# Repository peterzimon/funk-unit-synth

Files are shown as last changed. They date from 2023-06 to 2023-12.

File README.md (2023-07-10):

# Shmøergh Funk Live One — 6 voice paraphonic synthesizer

Shmøergh Funk Live One is a 6 voice (mostly) digitally controlled paraphonic
analog synthesizer. Its purposefully built with limitations so it's great for
live performances with quick changes in settings without presets or menu diving. It
has a lot of simple but effective ways to modulate the filter cutoff which makes
it great for funk performances. Because of its simplicity it's also cool to get
started with synthesis.

**Status:** WORK IN PROGRESS

**Latest version:** 1.1

## Features

- 6 voices (DCOs) controlled by a Raspberry Pi Pico
- Sawtooth, square, narrow pulse and fixed rate pulse with modulated square waveforms
- Analog signal path
- External filter connection with selectable various modulation sources (envelope, velocity, analog LFO, modwheel, keyboard tracking). Steiner-Parker
filter schematics and PCB is included
- 12bit digital ADSR with simplified envelope controls
- Built-in analog VCA with optional external VCA connections
- Monophonic, 3-voice unison with detune and 6-voice paraphonic modes
- MIDI input
- Eurorack compatible PCB sizing

Note: schematics does not include power supply

## References

- [Polykit DCO design](https://github.com/polykit/pico-dco)
- [The design of the Roland Juno synthesizes](https://blog.thea.codes/the-design-of-the-juno-dco/)
- [Steiner-Parker Filter](https://yusynth.net/Modular/EN/STEINERVCF/index-v2.html)

## License & info

Version: 1.1.0
Author: Peter Zimon
Copyright: 2023
Licence: MIT

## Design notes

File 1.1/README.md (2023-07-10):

# V1.1

- Added DC blocking to mixer inputs to avoid shifting waveforms by f=0Hz frequency DCOs
- Decreased sawtooth and square mixer amplification to avoid distortion

## License & info

Version: 1.0.0
Author: Peter Zimon
Copyright: 2023
Licence: MIT

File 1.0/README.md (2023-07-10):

# V1.0

- Complete schematics
- Fundamentals of code is implemented for handling 6 voices
- ADSR implemented
- MUX to handle switches
- All basic functionalities are working

# To Be Done

- Filter modulation is untested

## License & info

Version: 1.0.0
Author: Peter Zimon
Copyright: 2023
Licence: MIT

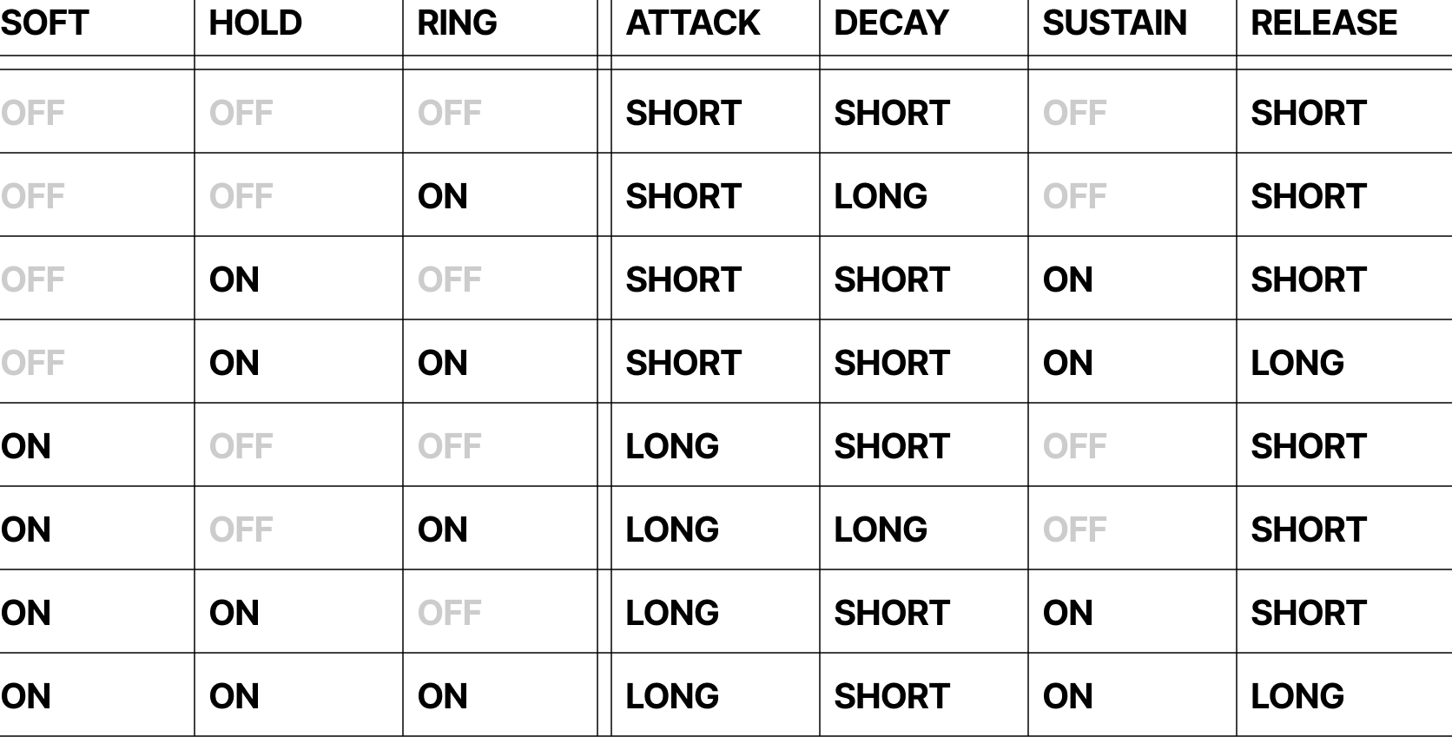
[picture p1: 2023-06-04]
1.0/docs/adsr-truthtable.png

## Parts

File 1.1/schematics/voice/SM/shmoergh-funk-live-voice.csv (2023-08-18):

Comment | Designator | Footprint | LCSC
100n | C1,C2,C3 | Capacitor_SMD:C_0805_2012Metric | C49678
4.7k | R1 | PCM_Resistor_SMD_AKL:R_0805_2012Metric | C17673
330k | R10 | PCM_Resistor_SMD_AKL:R_0805_2012Metric | C17629
15k | R12 | PCM_Resistor_SMD_AKL:R_0805_2012Metric | C17475
10k | R2,R13 | PCM_Resistor_SMD_AKL:R_0805_2012Metric | C17414
200k | R3,R7 | PCM_Resistor_SMD_AKL:R_0805_2012Metric | C17539
1k | R4 | PCM_Resistor_SMD_AKL:R_0805_2012Metric | C17513
2.2k | R5 | PCM_Resistor_SMD_AKL:R_0805_2012Metric | C17520
100k | R6,R11 | PCM_Resistor_SMD_AKL:R_0805_2012Metric | C149504
470k | R8,R9 | PCM_Resistor_SMD_AKL:R_0805_2012Metric | C17709

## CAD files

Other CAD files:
1.0/case/wooden-case-proto.blend

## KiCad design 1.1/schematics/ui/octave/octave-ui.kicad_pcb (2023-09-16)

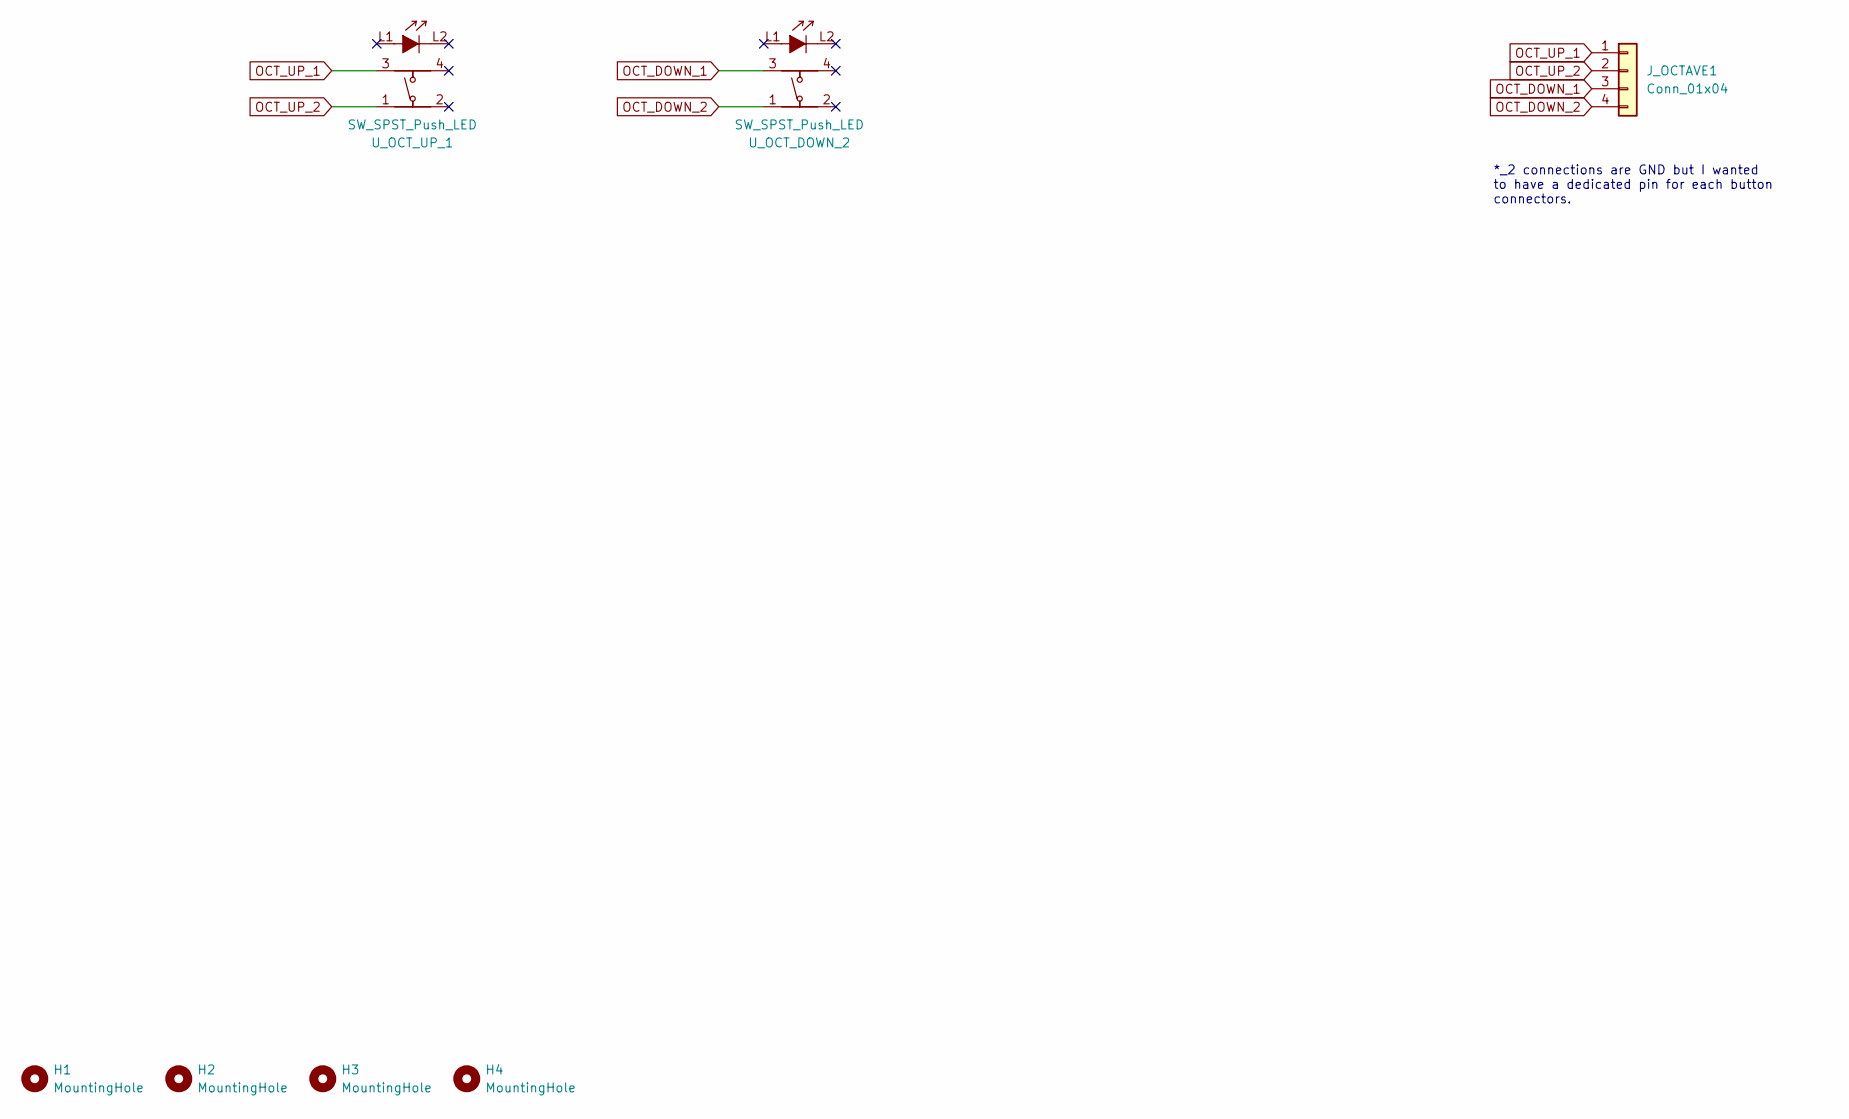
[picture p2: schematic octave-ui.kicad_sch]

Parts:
H1, H2, H3, H4: MountingHole; MountingHole_4mm
J_OCTAVE1: Conn_01x04; NSL25_01x04_Vertical
U_OCT_DOWN_2: SW_SPST_Push_LED; SPST_Narrow_Circular_Pushbutton_LED
U_OCT_UP_1: SW_SPST_Push_LED; SPST_Narrow_Circular_Pushbutton_LED

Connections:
OCT_DOWN_1: J_OCTAVE1.3, U_OCT_DOWN_2.3
OCT_DOWN_2: J_OCTAVE1.4, U_OCT_DOWN_2.1
OCT_UP_1: J_OCTAVE1.1, U_OCT_UP_1.3
OCT_UP_2: J_OCTAVE1.2, U_OCT_UP_1.1

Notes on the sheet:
*_2 connections are GND but I wanted to have a dedicated pin for each button connectors.

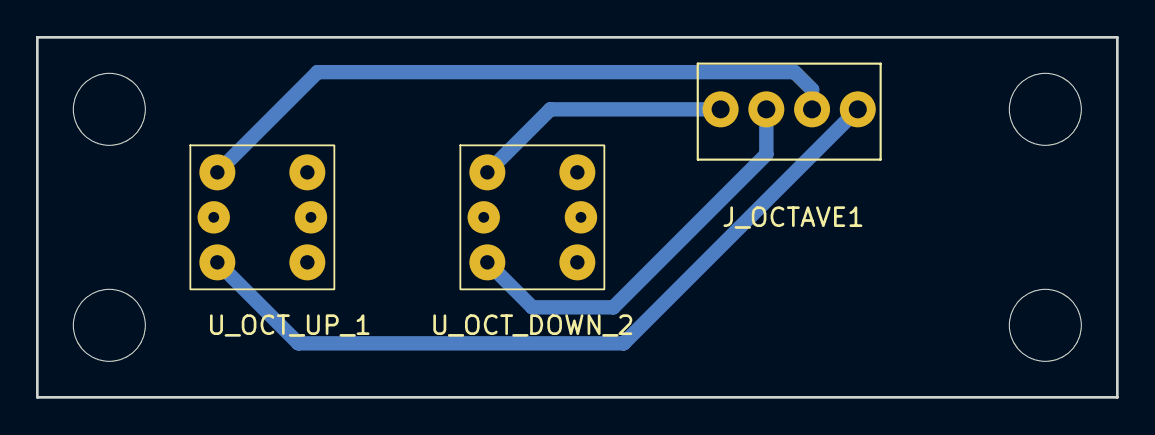
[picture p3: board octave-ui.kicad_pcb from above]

Board: 2 copper layers, 60.0 x 20.0 mm, 7 parts (0 on the bottom side), 4 nets.

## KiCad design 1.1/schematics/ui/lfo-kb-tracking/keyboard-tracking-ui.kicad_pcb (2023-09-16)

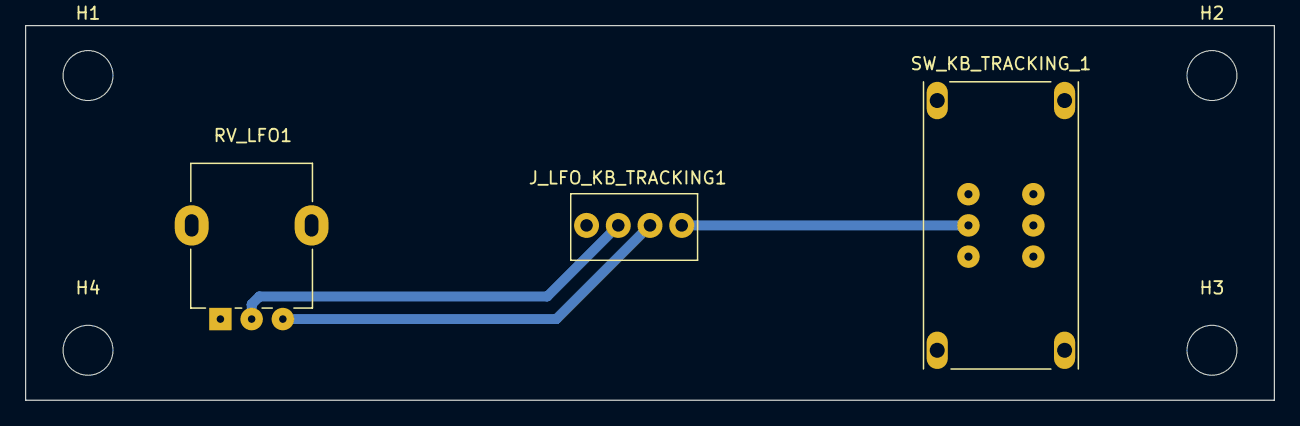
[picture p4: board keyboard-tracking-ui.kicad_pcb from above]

Board: 2 copper layers, 100.0 x 30.0 mm, 7 parts (0 on the bottom side), 4 nets.

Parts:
H1, H2, H3, H4: MountingHole; MountingHole_4mm
J_LFO_KB_TRACKING1: Conn_01x04; NSL25_01x04_Vertical
RV_LFO1: 100k; Potentiometer_Alpha_RD901F-40-00D_Single_Vertical
SW_KB_TRACKING_1: SW_DPDT_x2; DPDT Korg Style Switch

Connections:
GND: J_LFO_KB_TRACKING1.4, RV_LFO1.1, SW_KB_TRACKING_1.5 (C)
KB_TRACKING: J_LFO_KB_TRACKING1.1, SW_KB_TRACKING_1.3 (B)
LFO_IN: J_LFO_KB_TRACKING1.2, RV_LFO1.3
LFO_OUT: J_LFO_KB_TRACKING1.3, RV_LFO1.2

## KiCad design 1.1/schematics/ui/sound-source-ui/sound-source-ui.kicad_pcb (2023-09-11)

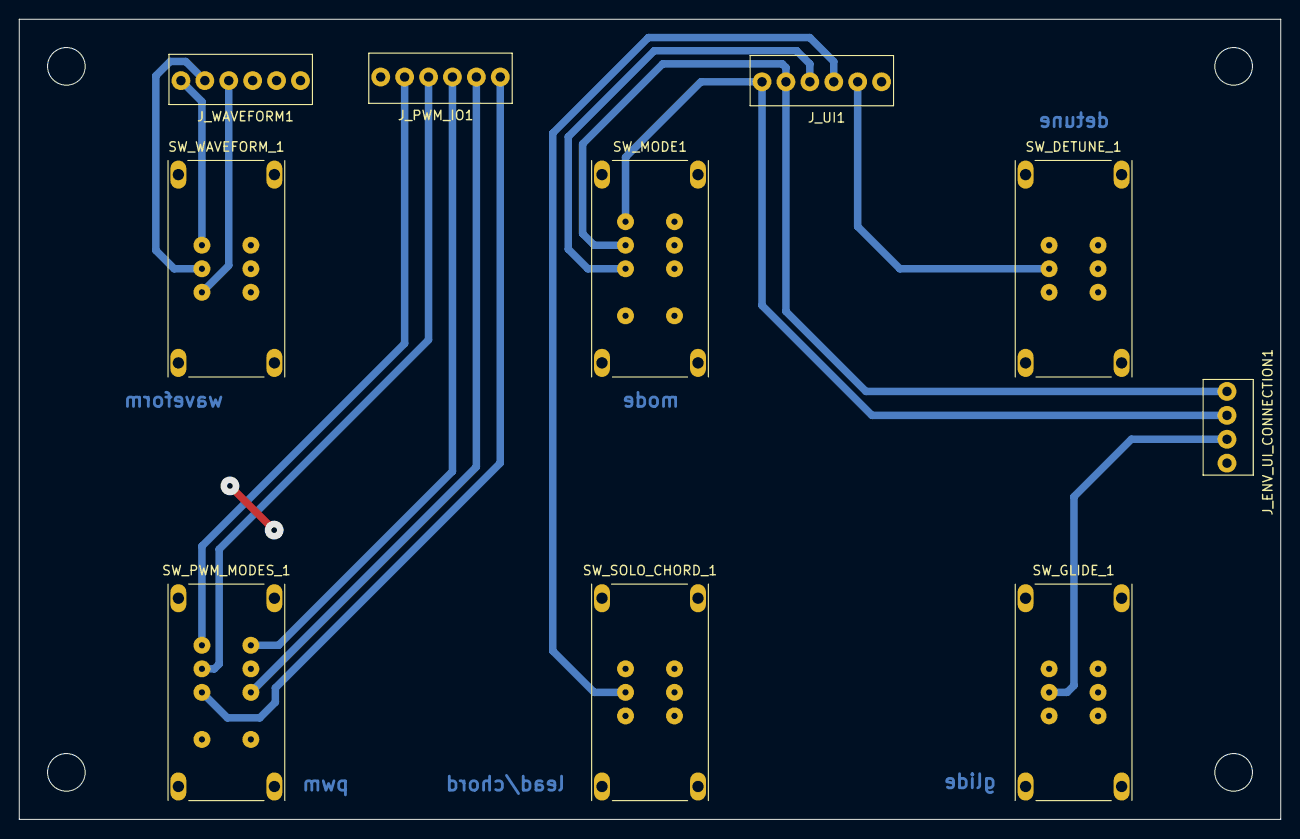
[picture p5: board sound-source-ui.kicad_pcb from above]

Board: 2 copper layers, 134.0 x 85.0 mm, 14 parts (0 on the bottom side), 15 nets.

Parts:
H1, H2, H3, H4: MountingHole; MountingHole_4mm
J_ENV_UI_CONNECTION1: Conn_01x04; NSL25_01x04_Vertical
J_PWM_IO1: Conn_01x06; NSL25_01x06_Vertical
J_UI1: Conn_01x06; NSL25_01x06_Vertical
J_WAVEFORM1: Conn_01x03; NSL25_01x06_Vertical
SW_DETUNE_1: SW_DPDT_x2; DPDT Korg Style Switch
SW_GLIDE_1: SW_DPDT_x2; DPDT Korg Style Switch
SW_MODE1: SW_DP3T; DP3T Korg Style Switch
SW_PWM_MODES_1: SW_DP3T; DP3T Korg Style Switch
SW_SOLO_CHORD_1: SW_DPDT_x2; DPDT Korg Style Switch
SW_WAVEFORM_1: SW_DPDT_x2; DPDT Korg Style Switch

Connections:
1.5V: J_ENV_UI_CONNECTION1.1, J_UI1.2, SW_MODE1.2
+3.3V: J_ENV_UI_CONNECTION1.2, J_UI1.1, SW_MODE1.1
DETUNE: J_UI1.5, SW_DETUNE_1.3 (B)
GLIDE: J_ENV_UI_CONNECTION1.3, SW_GLIDE_1.3 (B)
GND: J_ENV_UI_CONNECTION1.4, J_PWM_IO1.6, J_UI1.6, SW_DETUNE_1.5 (C), SW_GLIDE_1.5 (C), SW_MODE1.4, SW_PWM_MODES_1.4, SW_PWM_MODES_1.6, SW_PWM_MODES_1.8, SW_SOLO_CHORD_1.5 (C)
MODE: J_UI1.3, SW_MODE1.3
PULSE_WIDTH: J_PWM_IO1.1, SW_PWM_MODES_1.3
PWM_LFO: J_PWM_IO1.3, SW_PWM_MODES_1.5
PWM_LFO_BIAS: J_PWM_IO1.5, SW_PWM_MODES_1.1
PWM_NARROW_BIAS: J_PWM_IO1.4, SW_PWM_MODES_1.2
PWM_OUT: J_PWM_IO1.2, SW_PWM_MODES_1.7
SAW_IN: J_WAVEFORM1.3, SW_WAVEFORM_1.5 (C)
SOLO_CHORD: J_UI1.4, SW_SOLO_CHORD_1.3 (B)
SQR_IN: J_WAVEFORM1.1, SW_WAVEFORM_1.1 (A)
WAVEFORM_OUT: J_WAVEFORM1.2, SW_WAVEFORM_1.3 (B)

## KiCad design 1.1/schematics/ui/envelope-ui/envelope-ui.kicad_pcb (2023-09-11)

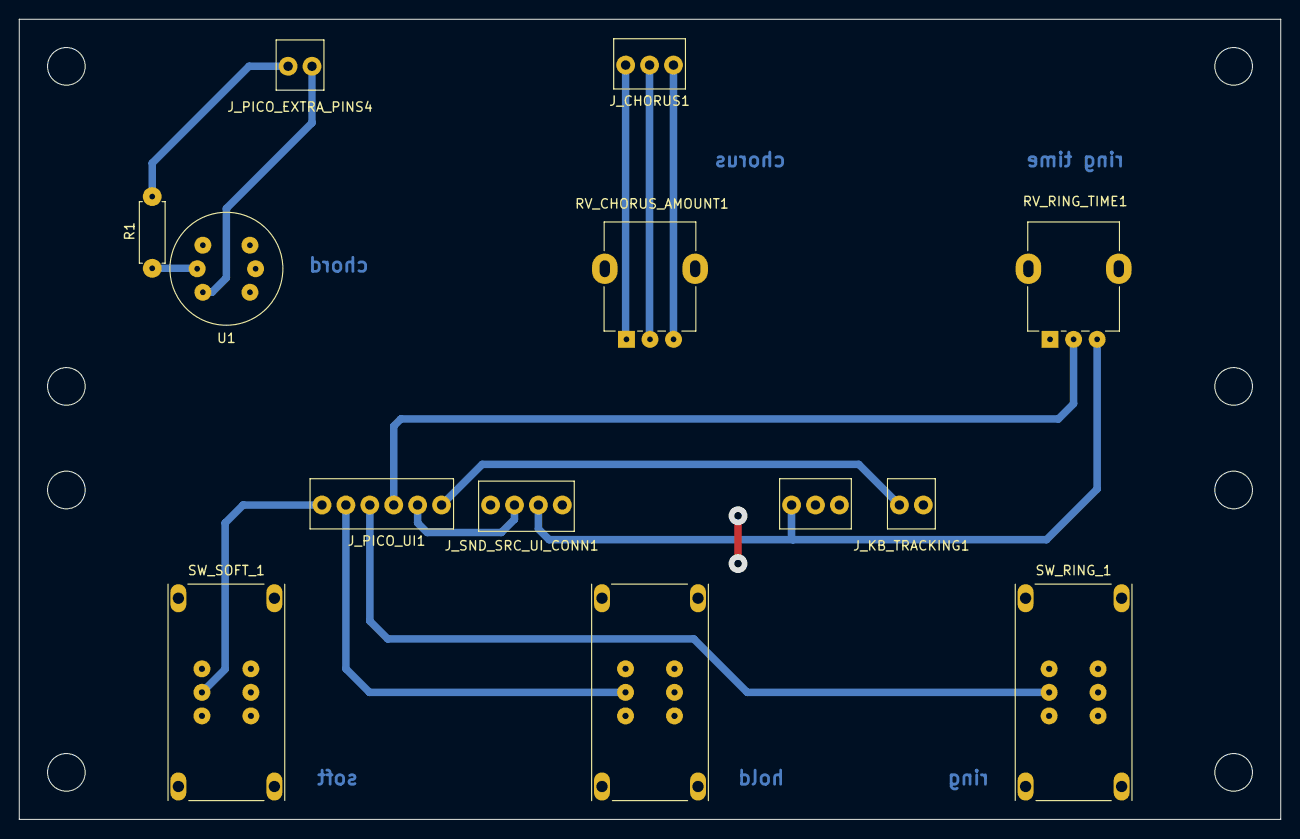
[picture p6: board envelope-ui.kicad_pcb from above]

Board: 2 copper layers, 134.0 x 85.0 mm, 21 parts (0 on the bottom side), 14 nets.

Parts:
H1, H2, H3, H4, H5, H6, H7, H8: MountingHole; MountingHole_4mm
J_CHORUS1: Conn_01x03; NSL25_01x03_Vertical
J_KB_TRACKING1: Conn_01x02; NSL25_01x02_Vertical
J_PICO_EXTRA_PINS4: Conn_01x02; NSL25_01x02_Vertical
J_PICO_UI1: Conn_01x06; NSL25_01x06_Vertical
J_PWR1: Conn_01x03; NSL25_01x03_Vertical
J_SND_SRC_UI_CONN1: Conn_01x04; NSL25_01x04_Vertical
R1: R; R_Axial_DIN0207_L6.3mm_D2.5mm_P7.62mm_Horizontal
RV_CHORUS_AMOUNT1: 100k; Potentiometer_Alpha_RD901F-40-00D_Single_Vertical
RV_RING_TIME1: 100k; Potentiometer_Alpha_RD901F-40-00D_Single_Vertical
SW_HOLD_1: SW_DPDT_x2; DPDT Korg Style Switch
SW_RING_1: SW_DPDT_x2; DPDT Korg Style Switch
SW_SOFT_1: SW_DPDT_x2; DPDT Korg Style Switch
U1: SW_SPST_Push_LED; SPST_Circular_Pushbutton_LED

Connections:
+3.3V: J_PWR1.1, J_SND_SRC_UI_CONN1.2, RV_RING_TIME1.3
CHORD_BTN: J_PICO_EXTRA_PINS4.2, U1.3
CHORD_LED: J_PICO_EXTRA_PINS4.1, R1.1
CHORUS_1: J_CHORUS1.1, RV_CHORUS_AMOUNT1.1
CHORUS_2: J_CHORUS1.2, RV_CHORUS_AMOUNT1.2
CHORUS_3: J_CHORUS1.3, RV_CHORUS_AMOUNT1.3
GLIDE: J_PICO_UI1.5, J_SND_SRC_UI_CONN1.3
GND: J_KB_TRACKING1.2, J_PWR1.2, J_PWR1.3, J_SND_SRC_UI_CONN1.4, RV_RING_TIME1.1, SW_HOLD_1.5 (C), SW_RING_1.5 (C), SW_SOFT_1.5 (C), U1.1, U1.L2
HOLD: J_PICO_UI1.2, SW_HOLD_1.3 (B)
KB_TRACKING: J_KB_TRACKING1.1, J_PICO_UI1.6
unnamed: R1.2, U1.L1
RING: J_PICO_UI1.3, SW_RING_1.3 (B)
RING_TIME: J_PICO_UI1.4, RV_RING_TIME1.2
SOFT: J_PICO_UI1.1, SW_SOFT_1.3 (B)

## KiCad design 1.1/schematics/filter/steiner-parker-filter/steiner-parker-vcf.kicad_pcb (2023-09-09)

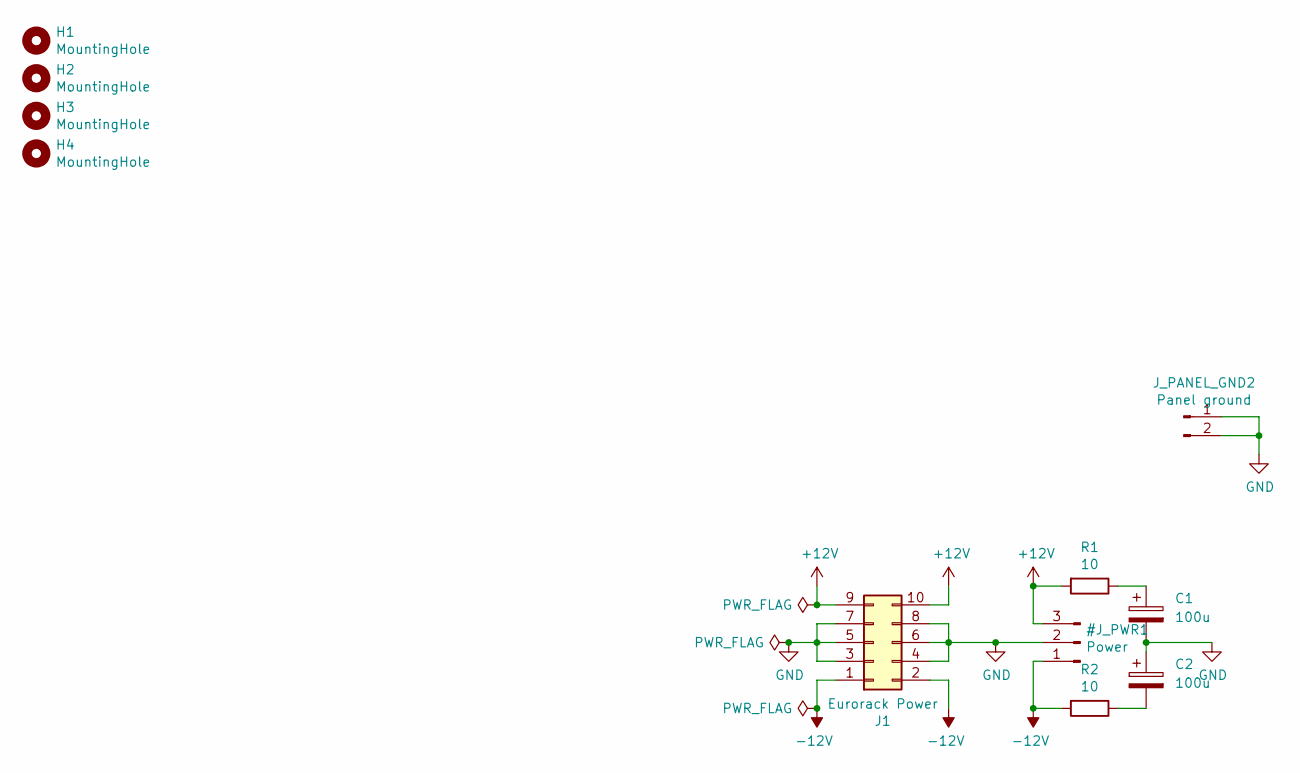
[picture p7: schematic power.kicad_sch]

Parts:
C1, C2: 100u; CP_Radial_D6.3mm_P2.50mm
H1, H2, H3, H4: MountingHole; MountingHole_3mm_Pad
J1: Eurorack Power; IDC-Header_2x05_P2.54mm_Vertical
J_PANEL_GND2: Panel ground; NSL25_01x02_Vertical
R1, R2: 10; R_Axial_DIN0207_L6.3mm_D2.5mm_P7.62mm_Horizontal

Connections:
unnamed: C1.1, R1.1
unnamed: C2.2, R2.1

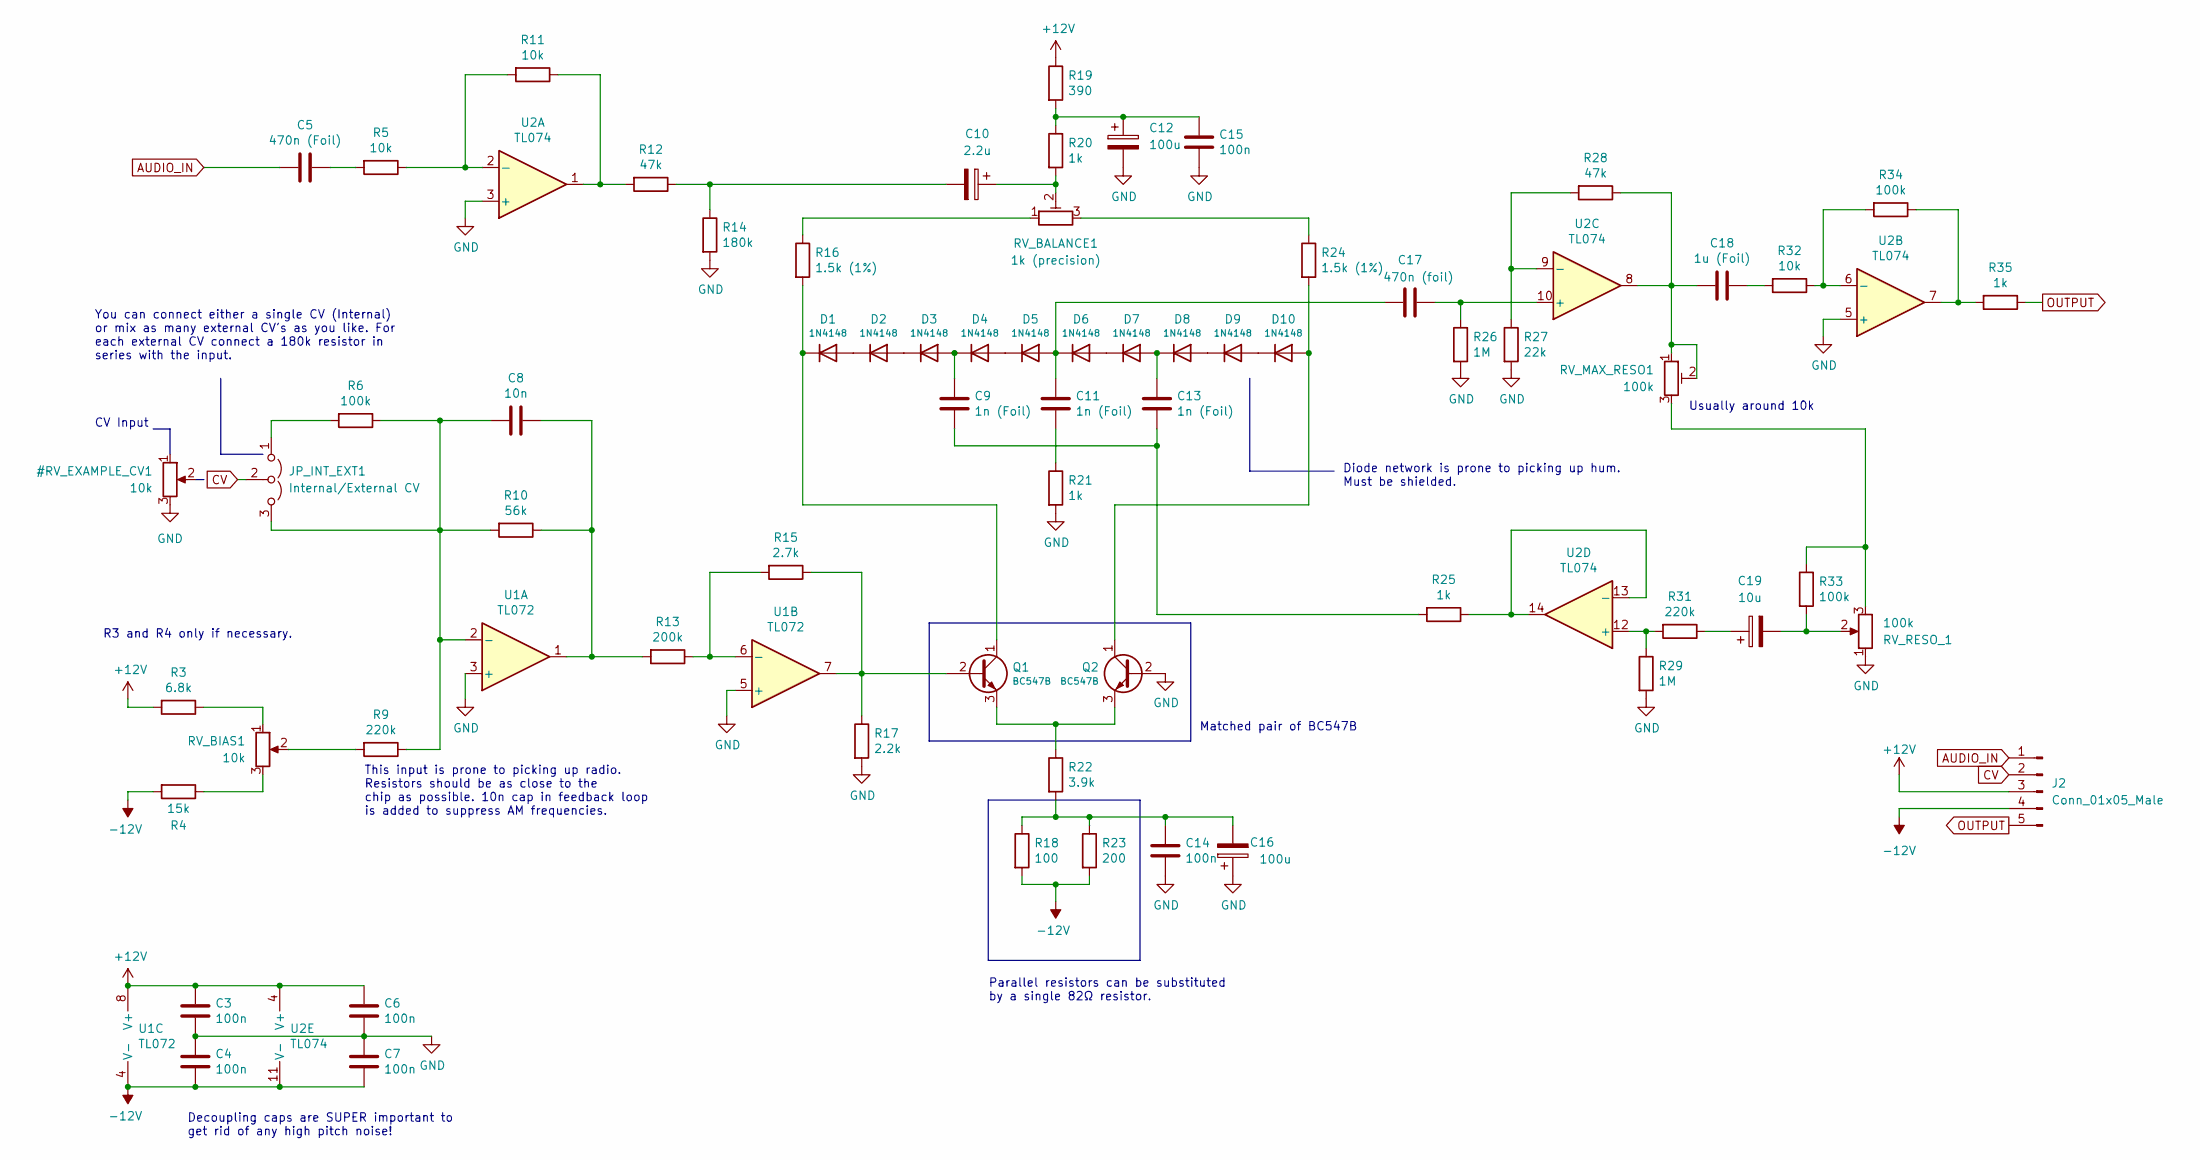
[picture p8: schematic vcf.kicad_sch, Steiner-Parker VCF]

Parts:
C3, C4, C6, C7, C14, C15: 100n; C_Disc_D3.0mm_W2.0mm_P2.50mm
C5: 470n (Foil); C_Rect_L7.0mm_W2.5mm_P5.00mm
C8: 10n; C_Disc_D3.0mm_W2.0mm_P2.50mm
C9, C11, C13: 1n (Foil); C_Rect_L7.0mm_W2.5mm_P5.00mm
C10: 2.2u; CP_Radial_D6.3mm_P2.50mm
C12, C16: 100u; CP_Radial_D6.3mm_P2.50mm
C17: 470n (foil); C_Rect_L7.0mm_W2.5mm_P5.00mm
C18: 1u (Foil); C_Rect_L7.0mm_W4.5mm_P5.00mm
C19: 10u; CP_Radial_D6.3mm_P2.50mm
D1, D2, D3, D4, D5, D6, D7, D8, D9, D10: 1N4148; D_DO-35_SOD27_P7.62mm_Horizontal
J2: Conn_01x05_Male; NSL25_01x05_Vertical
JP_INT_EXT1: Internal/External CV; PinSocket_1x03_P2.54mm_Vertical
Q1, Q2: BC547B; TO-92_Inline_Wide
R3: 6.8k; R_Axial_DIN0207_L6.3mm_D2.5mm_P7.62mm_Horizontal
R4: 15k; R_Axial_DIN0207_L6.3mm_D2.5mm_P7.62mm_Horizontal
R5, R11, R32: 10k; R_Axial_DIN0207_L6.3mm_D2.5mm_P7.62mm_Horizontal
R6, R33, R34: 100k; R_Axial_DIN0207_L6.3mm_D2.5mm_P7.62mm_Horizontal
R9, R31: 220k; R_Axial_DIN0207_L6.3mm_D2.5mm_P7.62mm_Horizontal
R10: 56k; R_Axial_DIN0207_L6.3mm_D2.5mm_P7.62mm_Horizontal
R12, R28: 47k; R_Axial_DIN0207_L6.3mm_D2.5mm_P7.62mm_Horizontal
R13: 200k; R_Axial_DIN0207_L6.3mm_D2.5mm_P7.62mm_Horizontal
R14: 180k; R_Axial_DIN0207_L6.3mm_D2.5mm_P7.62mm_Horizontal
R15: 2.7k; R_Axial_DIN0207_L6.3mm_D2.5mm_P7.62mm_Horizontal
R16, R24: 1.5k (1%); R_Axial_DIN0207_L6.3mm_D2.5mm_P7.62mm_Horizontal
R17: 2.2k; R_Axial_DIN0207_L6.3mm_D2.5mm_P7.62mm_Horizontal
R18: 100; R_Axial_DIN0207_L6.3mm_D2.5mm_P7.62mm_Horizontal
R19: 390; R_Axial_DIN0207_L6.3mm_D2.5mm_P7.62mm_Horizontal
R20, R21, R25, R35: 1k; R_Axial_DIN0207_L6.3mm_D2.5mm_P7.62mm_Horizontal
R22: 3.9k; R_Axial_DIN0207_L6.3mm_D2.5mm_P7.62mm_Horizontal
R23: 200; R_Axial_DIN0207_L6.3mm_D2.5mm_P7.62mm_Horizontal
R26, R29: 1M; R_Axial_DIN0207_L6.3mm_D2.5mm_P7.62mm_Horizontal
R27: 22k; R_Axial_DIN0207_L6.3mm_D2.5mm_P7.62mm_Horizontal
RV_BALANCE1: 1k (precision); Potentiometer_Bourns_3296W_Vertical
RV_BIAS1: 10k; Potentiometer_Runtron_RM-065_Vertical
RV_MAX_RESO1: 100k; Potentiometer_Runtron_RM-065_Vertical
RV_RESO_1: 100k; NSL25_01x03_Vertical
U1: TL072; DIP-8_W7.62mm_LongPads
U2: TL074; DIP-14_W7.62mm_LongPads

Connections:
AUDIO_IN: C5.2, J2.1
CV: J2.2, JP_INT_EXT1.2 (C)
unnamed: C5.1, R5.2
unnamed: C8.1, R10.1, R13.2, U1.1
unnamed: C10.1, R20.2, RV_BALANCE1.2
unnamed: C10.2, R12.1, R14.1
unnamed: C11.2, R21.1
unnamed: C12.1, C15.1, R19.2, R20.1
unnamed: C9.2, C13.2, R25.2
unnamed: C14.1, C16.2, R18.1, R22.2, R23.1
unnamed: C18.1, R32.2
unnamed: C18.2, R28.1, RV_MAX_RESO1.1, RV_MAX_RESO1.2, U2.8
unnamed: C19.1, R31.1
unnamed: C19.2, R33.2, RV_RESO_1.2
unnamed: D1.2 (A), D2.1 (K)
unnamed: D1.1 (K), Q1.1 (C), R16.2
unnamed: D2.2 (A), D3.1 (K)
unnamed: C9.1, D3.2 (A), D4.1 (K)
unnamed: D4.2 (A), D5.1 (K)
unnamed: C11.1, C17.2, D5.2 (A), D6.1 (K)
unnamed: D6.2 (A), D7.1 (K)
unnamed: C13.1, D7.2 (A), D8.1 (K)
unnamed: D8.2 (A), D9.1 (K)
unnamed: D10.2 (A), Q2.1 (C), R24.2
unnamed: D9.2 (A), D10.1 (K)
unnamed: JP_INT_EXT1.1 (A), R6.2
unnamed: C8.2, JP_INT_EXT1.3 (B), R6.1, R9.1, R10.2, U1.2 (-)
unnamed: Q1.2 (B), R15.1, R17.1, U1.7
unnamed: Q1.3 (E), Q2.3 (E), R22.1
unnamed: R3.1, RV_BIAS1.1
unnamed: R4.1, RV_BIAS1.3
unnamed: R9.2, RV_BIAS1.2
unnamed: R11.1, R12.2, U2.1
unnamed: R16.1, RV_BALANCE1.1
unnamed: R24.1, RV_BALANCE1.3
unnamed: R33.1, RV_MAX_RESO1.3, RV_RESO_1.3
unnamed: R34.1, R35.2, U2.7
unnamed: R13.1, R15.2, U1.6 (-)
unnamed: R5.1, R11.2, U2.2 (-)
unnamed: R32.1, R34.2, U2.6 (-)
unnamed: C17.1, R26.1, U2.10 (+)
unnamed: R27.1, R28.2, U2.9 (-)
unnamed: R29.1, R31.2, U2.12 (+)
unnamed: R25.1, U2.13 (-), U2.14
OUTPUT: J2.5, R35.1

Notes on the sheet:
CV Input
This input is prone to picking up radio. Resistors should be as close to the chip as possible. 10n cap in feedback loop is added to suppress AM frequencies.
Decoupling caps are SUPER important to get rid of any high pitch noise!
Matched pair of BC547B
R3 and R4 only if necessary.
Parallel resistors can be substituted by a single 82Ω resistor.
Usually around 10k
You can connect either a single CV (Internal) or mix as many external CV's as you like. For each external CV connect a 180k resistor in series with the input.
Diode network is prone to picking up hum. Must be shielded.

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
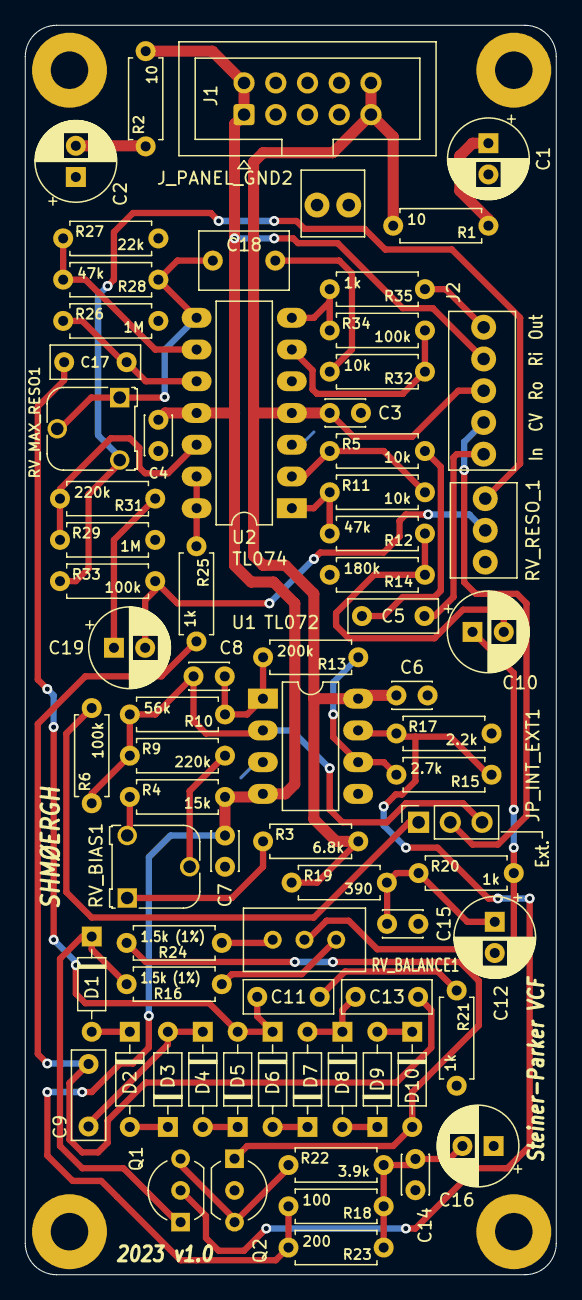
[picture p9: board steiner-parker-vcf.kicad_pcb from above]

Board: 2 copper layers, 42.5 x 100.0 mm, 77 parts (0 on the bottom side), 50 nets.

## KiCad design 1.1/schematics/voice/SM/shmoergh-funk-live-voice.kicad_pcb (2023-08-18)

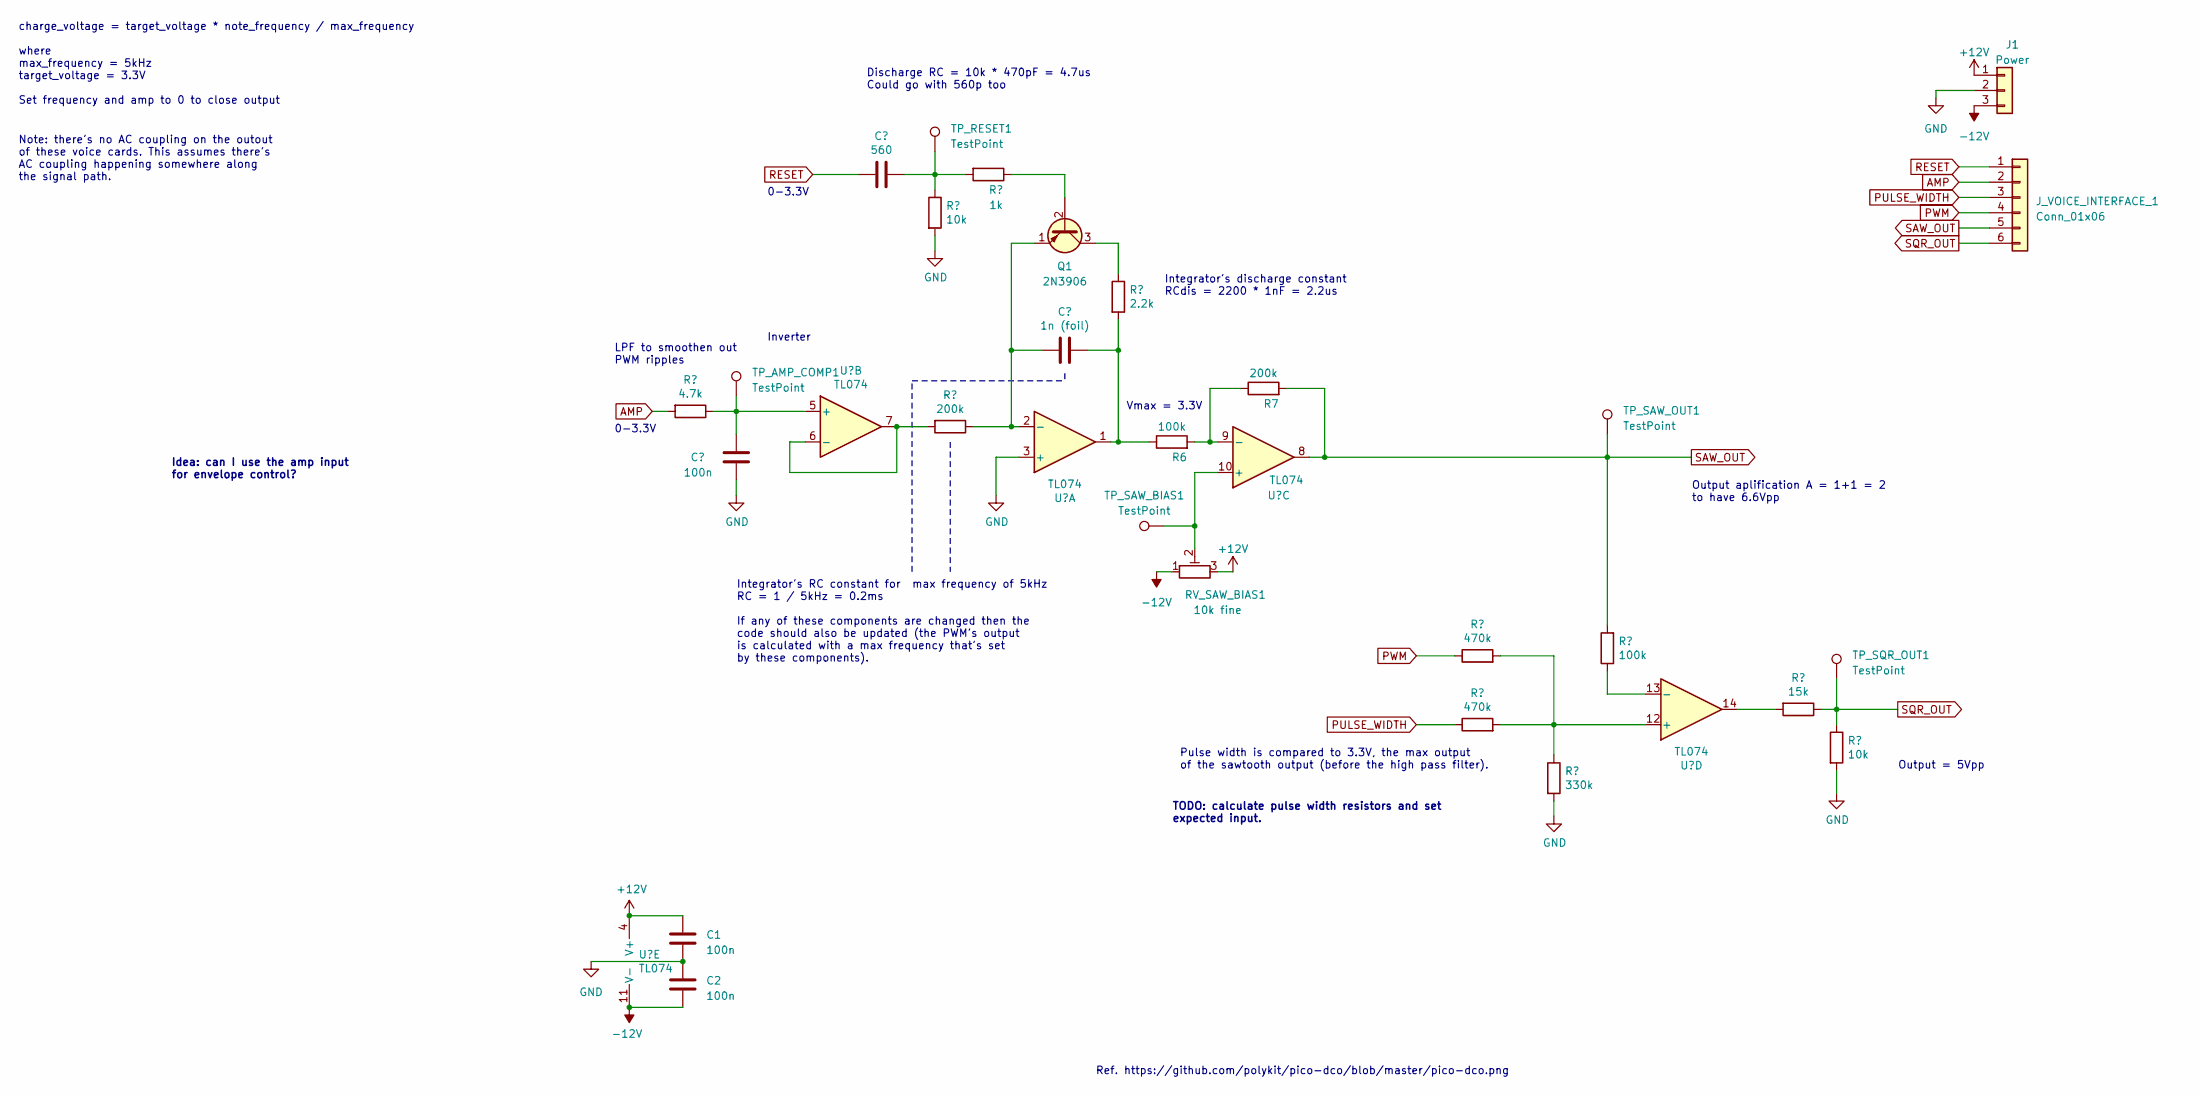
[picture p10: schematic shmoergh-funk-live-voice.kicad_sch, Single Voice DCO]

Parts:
C1, C2, C3: 100n; C_0805_2012Metric; LCSC C49678
C4: 560; C_Disc_D3.4mm_W2.1mm_P2.50mm
C5: 1n (foil); C_Rect_L7.2mm_W4.5mm_P5.00mm_FKS2_FKP2_MKS2_MKP2
J1: Power; PinHeader_1x03_P2.54mm_Vertical
J_VOICE_INTERFACE_1: Conn_01x06; PinHeader_1x06_P2.54mm_Vertical
Q1: 2N3906; TO-92L_Inline_Wide
R1: 4.7k; R_0805_2012Metric; LCSC C17673
R2, R13: 10k; R_0805_2012Metric; LCSC C17414
R3, R7: 200k; R_0805_2012Metric; LCSC C17539
R4: 1k; R_0805_2012Metric; LCSC C17513
R5: 2.2k; R_0805_2012Metric; LCSC C17520
R6, R11: 100k; R_0805_2012Metric; LCSC C149504
R8, R9: 470k; R_0805_2012Metric; LCSC C17709
R10: 330k; R_0805_2012Metric; LCSC C17629
R12: 15k; R_0805_2012Metric; LCSC C17475
RV_SAW_BIAS1: 10k fine; Potentiometer_ACP_CA6-H2,5_Horizontal
TP_AMP_COMP1: TestPoint; Pin_D0.7mm_L6.5mm_W1.8mm_FlatFork
TP_RESET1: TestPoint; Pin_D0.7mm_L6.5mm_W1.8mm_FlatFork
TP_SAW_BIAS1: TestPoint; Pin_D0.7mm_L6.5mm_W1.8mm_FlatFork
TP_SAW_OUT1: TestPoint; Pin_D0.7mm_L6.5mm_W1.8mm_FlatFork
TP_SQR_OUT1: TestPoint; Pin_D0.7mm_L6.5mm_W1.8mm_FlatFork
U1: TL074; DIP-14_W7.62mm_Socket_LongPads

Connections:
+12V: C1.1, J1.1, RV_SAW_BIAS1.3, U1.4 (V+)
-12V: C2.2, J1.3, RV_SAW_BIAS1.1, U1.11 (V-)
AMP: J_VOICE_INTERFACE_1.2, R1.2
GND: C1.2, C2.1, C3.2, J1.2, R2.2, R10.2, R13.2, U1.3 (+)
unnamed: C4.1, R2.1, R4.2, TP_RESET1.1
unnamed: C5.1, R5.2, R6.1, U1.1
unnamed: Q1.2 (B), R4.1
unnamed: Q1.3 (C), R5.1
unnamed: C5.2, Q1.1 (E), R3.1, U1.2 (-)
unnamed: R12.2, U1.14
unnamed: C3.1, R1.1, TP_AMP_COMP1.1, U1.5 (+)
unnamed: R3.2, U1.6 (-), U1.7
unnamed: RV_SAW_BIAS1.2, TP_SAW_BIAS1.1, U1.10 (+)
unnamed: R6.2, R7.1, U1.9 (-)
unnamed: R8.2, R9.2, R10.1, U1.12 (+)
unnamed: R11.1, U1.13 (-)
PULSE_WIDTH: J_VOICE_INTERFACE_1.3, R9.1
PWM: J_VOICE_INTERFACE_1.4, R8.1
RESET: C4.2, J_VOICE_INTERFACE_1.1
SAW_OUT: J_VOICE_INTERFACE_1.5, R7.2, R11.2, TP_SAW_OUT1.1, U1.8
SQR_OUT: J_VOICE_INTERFACE_1.6, R12.1, R13.1, TP_SQR_OUT1.1

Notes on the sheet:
Pulse width is compared to 3.3V, the max output of the sawtooth output (before the high pass filter).
Inverter
Idea: can I use the amp input for envelope control?
Vmax = 3.3V
TODO: calculate pulse width resistors and set expected input.
Output = 5Vpp
0-3.3V
charge_voltage = target_voltage * note_frequency / max_frequency where max_frequency = 5kHz target_voltage = 3.3V Set frequency and amp to 0 to close output
Output aplification A = 1+1 = 2 to have 6.6Vpp
Integrator's discharge constant RCdis = 2200 * 1nF = 2.2us
Note: there's no AC coupling on the outout of these voice cards. This assumes there's AC coupling happening somewhere along the signal path.
LPF to smoothen out PWM ripples
Discharge RC = 10k * 470pF = 4.7us Could go with 560p too
Integrator's RC constant for max frequency of 5kHz RC = 1 / 5kHz = 0.2ms If any of these components are changed then the code should also be updated (the PWM's output is calculated with a max frequency that's set by these components).
Ref. https://github.com/polykit/pico-dco/blob/master/pico-dco.png

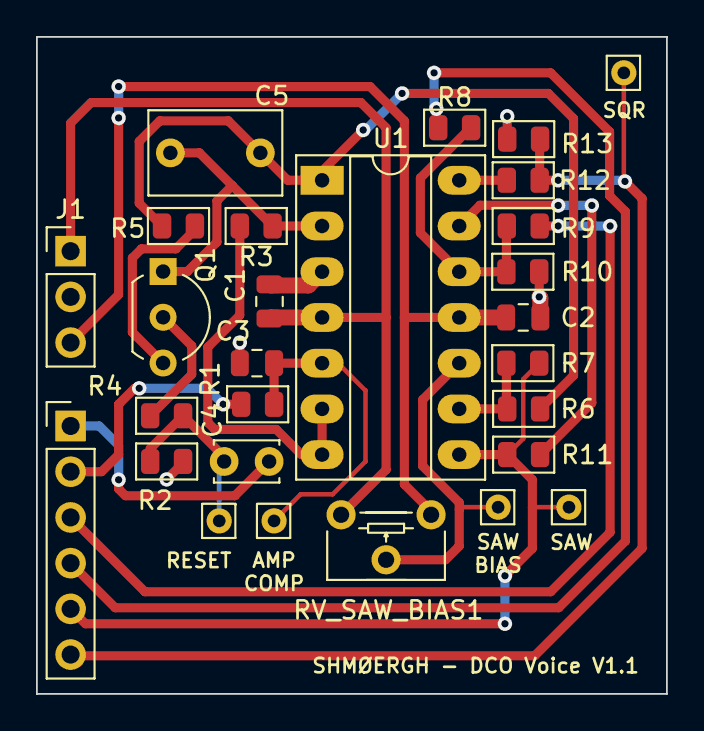
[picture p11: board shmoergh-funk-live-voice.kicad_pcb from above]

Board: 2 copper layers, 35.0 x 36.5 mm, 28 parts (0 on the bottom side), 21 nets.

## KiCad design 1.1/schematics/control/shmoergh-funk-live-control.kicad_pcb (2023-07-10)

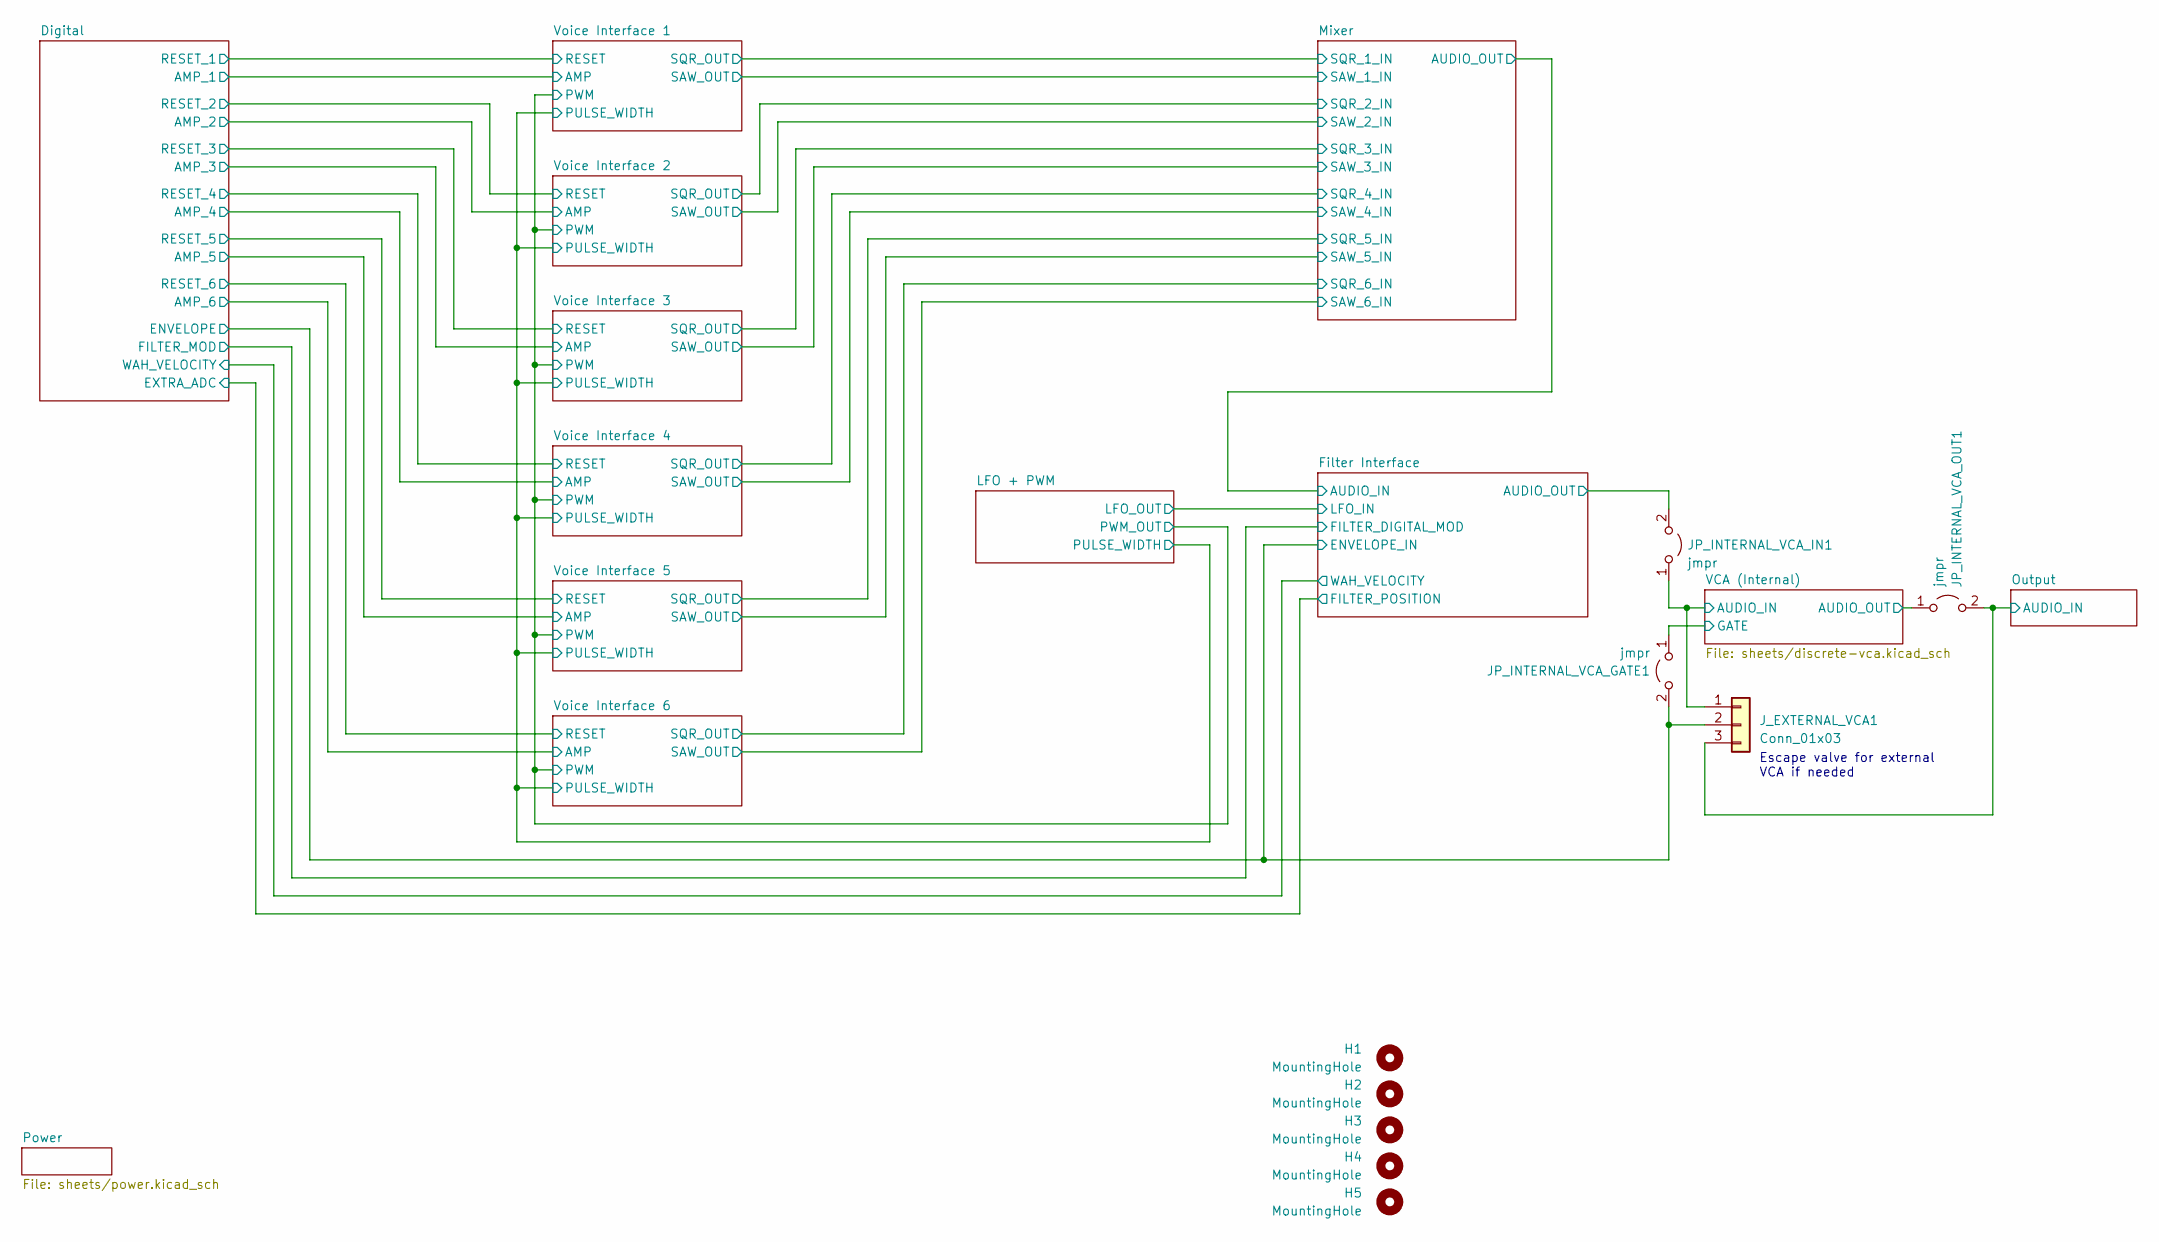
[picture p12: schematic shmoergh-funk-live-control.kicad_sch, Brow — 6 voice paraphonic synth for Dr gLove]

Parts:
H1, H2, H3, H4, H5: MountingHole; MountingHole_3mm_Pad
JP_INTERNAL_VCA_GATE1: jmpr; Jumper_P2.54mm_D0.7mm
JP_INTERNAL_VCA_IN1: jmpr; Jumper_P2.54mm_D0.7mm
JP_INTERNAL_VCA_OUT1: jmpr; Jumper_P2.54mm_D0.7mm
J_EXTERNAL_VCA1: Conn_01x03; NSL25_01x03_Vertical

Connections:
/Filter Interface/AUDIO_OUT: JP_INTERNAL_VCA_IN1.2 (B); also elsewhere on the board
/Output/AUDIO_IN: JP_INTERNAL_VCA_OUT1.2 (B), J_EXTERNAL_VCA1.3; also elsewhere on the board
/VCA (Internal)/AUDIO_IN: JP_INTERNAL_VCA_IN1.1 (A), J_EXTERNAL_VCA1.1; also elsewhere on the board
/VCA (Internal)/AUDIO_OUT: JP_INTERNAL_VCA_OUT1.1 (A); also elsewhere on the board

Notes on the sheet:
Escape valve for external VCA if needed

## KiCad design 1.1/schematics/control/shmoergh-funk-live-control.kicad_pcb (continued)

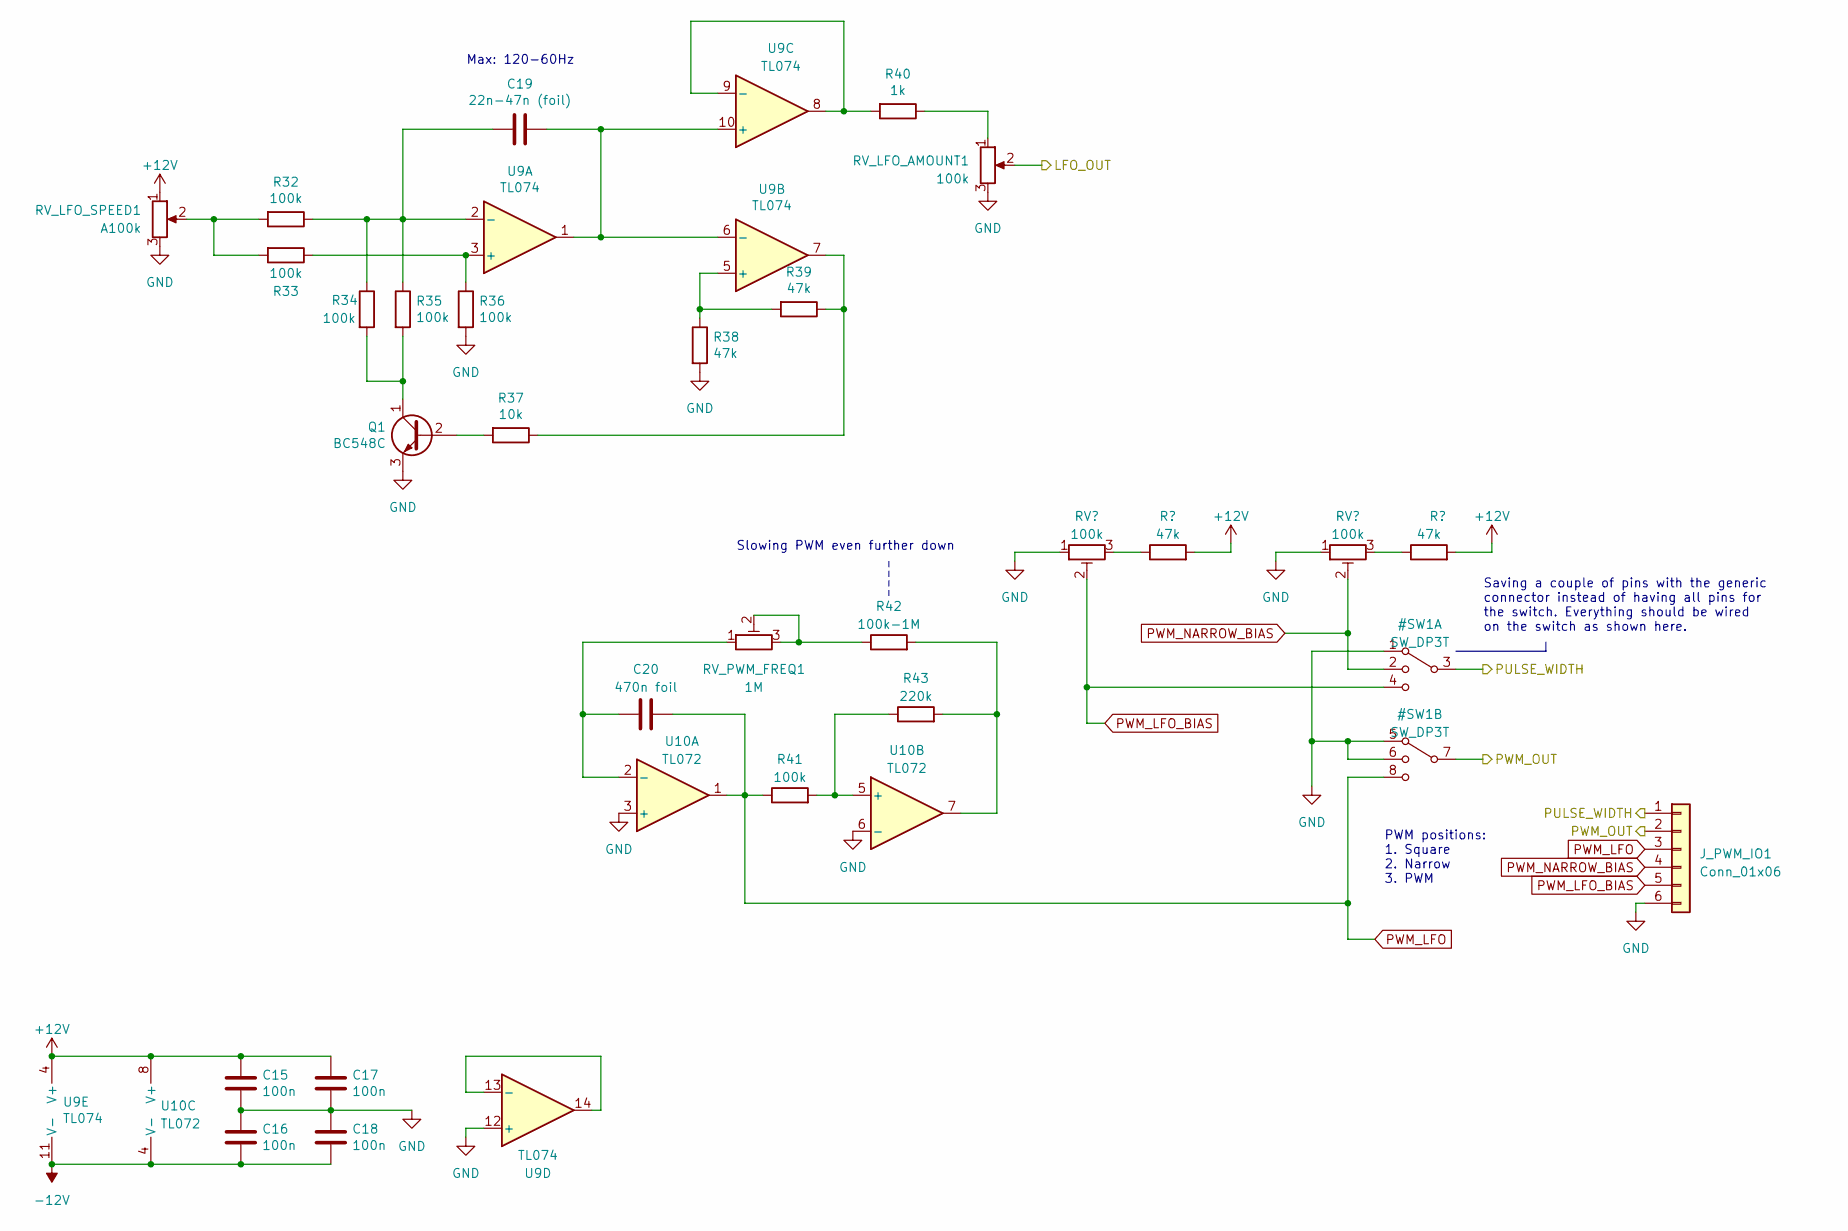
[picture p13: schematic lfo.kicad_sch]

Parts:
C15, C16, C17, C18: 100n; C_Disc_D3.0mm_W2.0mm_P2.50mm
C19: 22n-47n (foil); C_Rect_L7.0mm_W3.5mm_P5.00mm
C20: 470n foil; C_Rect_L7.0mm_W3.5mm_P5.00mm
J_PWM_IO1: Conn_01x06; NSL25_01x06_Vertical
Q1: BC548C; TO-92_Inline_Wide
R32, R33, R34, R35, R36, R41: 100k; R_Axial_DIN0207_L6.3mm_D2.5mm_P7.62mm_Horizontal
R37: 10k; R_Axial_DIN0207_L6.3mm_D2.5mm_P7.62mm_Horizontal
R38, R39, R44, R45: 47k; R_Axial_DIN0207_L6.3mm_D2.5mm_P7.62mm_Horizontal
R40: 1k; R_Axial_DIN0207_L6.3mm_D2.5mm_P7.62mm_Horizontal
R42: 100k-1M; R_Axial_DIN0207_L6.3mm_D2.5mm_P7.62mm_Horizontal
R43: 220k; R_Axial_DIN0207_L6.3mm_D2.5mm_P7.62mm_Horizontal
RV_LFO_AMOUNT1: 100k; NSL25_01x03_Vertical
RV_LFO_SPEED1: A100k; NSL25_01x03_Vertical
RV_NARROW_BIAS1: 100k; Potentiometer_Runtron_RM-065_Vertical
RV_PWM_BIAS1: 100k; Potentiometer_Runtron_RM-065_Vertical
RV_PWM_FREQ1: 1M; Potentiometer_Runtron_RM-065_Vertical
U9: TL074; DIP-14_W7.62mm_LongPads
U10: TL072; DIP-8_W7.62mm_LongPads

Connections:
-12V: C16.2, C18.2, U9.11 (V-), U10.4 (V-); also elsewhere on the board
unnamed: Q1.2 (B), R37.2
unnamed: Q1.1 (C), R34.2, R35.2
unnamed: R32.2, R33.2, RV_LFO_SPEED1.2
unnamed: R37.1, R39.1, U9.7
unnamed: R40.1, RV_LFO_AMOUNT1.1
unnamed: R42.1, RV_PWM_FREQ1.2, RV_PWM_FREQ1.3
unnamed: R42.2, R43.2, U10.7
unnamed: R44.1, RV_PWM_BIAS1.3
unnamed: R45.1, RV_NARROW_BIAS1.3
unnamed: R33.1, R36.1, U9.3 (+)
unnamed: C19.2, R32.1, R34.1, R35.1, U9.2 (-)
unnamed: R38.1, R39.2, U9.5 (+)
unnamed: C19.1, U9.1, U9.6 (-), U9.10 (+)
unnamed: R40.2, U9.8, U9.9 (-)
unnamed: U9.13 (-), U9.14
unnamed: C20.1, RV_PWM_FREQ1.1, U10.2 (-)
unnamed: R41.2, R43.1, U10.5 (+)

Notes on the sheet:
Saving a couple of pins with the generic connector instead of having all pins for the switch. Everything should be wired on the switch as shown here.
Max: 120-60Hz
PWM positions: 1. Square 2. Narrow 3. PWM
Slowing PWM even further down


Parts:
J1: Power; PinHeader_2x03_P2.54mm_Vertical
J_VOICE_INTERFACE_2: Conn_01x06; PinHeader_1x06_P2.54mm_Vertical

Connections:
-12V: J1.5, J1.6; also elsewhere on the board
/Digital/AMP_2: J_VOICE_INTERFACE_2.2; also elsewhere on the board
/Digital/RESET_2: J_VOICE_INTERFACE_2.1; also elsewhere on the board
/Mixer/SAW_2_IN: J_VOICE_INTERFACE_2.5; also elsewhere on the board
/Mixer/SQR_2_IN: J_VOICE_INTERFACE_2.6; also elsewhere on the board

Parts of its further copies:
J2, J3, J4, J5, J6: Power; PinHeader_2x03_P2.54mm_Vertical
J_VOICE_INTERFACE_1, J_VOICE_INTERFACE_3, J_VOICE_INTERFACE_4, J_VOICE_INTERFACE_5, J_VOICE_INTERFACE_6: Conn_01x06; PinHeader_1x06_P2.54mm_Vertical

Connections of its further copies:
-12V: J2.5, J2.6, J3.5, J3.6, J4.5, J4.6, J5.5, J5.6, J6.5, J6.6; also elsewhere on the board
/Digital/AMP_1: J_VOICE_INTERFACE_1.2; also elsewhere on the board
/Digital/AMP_3: J_VOICE_INTERFACE_3.2; also elsewhere on the board
/Digital/AMP_4: J_VOICE_INTERFACE_4.2; also elsewhere on the board
/Digital/AMP_5: J_VOICE_INTERFACE_5.2; also elsewhere on the board
/Digital/AMP_6: J_VOICE_INTERFACE_6.2; also elsewhere on the board
/Digital/RESET_1: J_VOICE_INTERFACE_1.1; also elsewhere on the board
/Digital/RESET_3: J_VOICE_INTERFACE_3.1; also elsewhere on the board
/Digital/RESET_4: J_VOICE_INTERFACE_4.1; also elsewhere on the board
/Digital/RESET_5: J_VOICE_INTERFACE_5.1; also elsewhere on the board
/Digital/RESET_6: J_VOICE_INTERFACE_6.1; also elsewhere on the board
/Mixer/SAW_1_IN: J_VOICE_INTERFACE_1.5; also elsewhere on the board
/Mixer/SAW_3_IN: J_VOICE_INTERFACE_3.5; also elsewhere on the board
/Mixer/SAW_4_IN: J_VOICE_INTERFACE_4.5; also elsewhere on the board
/Mixer/SAW_5_IN: J_VOICE_INTERFACE_5.5; also elsewhere on the board
/Mixer/SAW_6_IN: J_VOICE_INTERFACE_6.5; also elsewhere on the board
/Mixer/SQR_1_IN: J_VOICE_INTERFACE_1.6; also elsewhere on the board
/Mixer/SQR_3_IN: J_VOICE_INTERFACE_3.6; also elsewhere on the board
/Mixer/SQR_4_IN: J_VOICE_INTERFACE_4.6; also elsewhere on the board
/Mixer/SQR_5_IN: J_VOICE_INTERFACE_5.6; also elsewhere on the board
/Mixer/SQR_6_IN: J_VOICE_INTERFACE_6.6; also elsewhere on the board


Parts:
C21, C22: 100u; CP_Radial_D6.3mm_P2.50mm
C23: 10u; CP_Radial_D6.3mm_P2.50mm
C24: 330n; C_Disc_D3.0mm_W2.0mm_P2.50mm
C25: 100n; C_Disc_D3.0mm_W2.0mm_P2.50mm
D2: 1N4001; D_DO-41_SOD81_P7.62mm_Horizontal
JP_INTERNAL_VCA_GATE1: jmpr; Jumper_P2.54mm_D0.7mm
J_PANEL_GND1: Conn_01x03_Pin; NSL25_01x03_Vertical
J_POWER1: Euro Power; IDC-Header_2x05_P2.54mm_Vertical
U11: L7805; TO-220-3_Vertical

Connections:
+5V: C25.1, U11.3 (OUT); also elsewhere on the board
-12V: C22.2, J_POWER1.1, J_POWER1.2; also elsewhere on the board
unnamed: C23.1, C24.1, D2.1 (K), U11.1 (IN)

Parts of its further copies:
JP_MCU_EXT_PWR2: jmpr; Jumper_P2.54mm_D0.7mm

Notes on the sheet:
This jumper MUST be removed before flashing!


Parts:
C11, C12, C13, C14: 100n; C_Disc_D3.0mm_W2.0mm_P2.50mm
D_NEGATIVE_LIMITER1: Red LED; LED_D5.0mm
J_HEADPHONES1: 3.5mm jack; NSL25_01x02_Vertical-AudioJack-TS
J_LINE_OUT1: 3.5mm jack; NSL25_01x02_Vertical-AudioJack-TS
R27: 22k; R_Axial_DIN0207_L6.3mm_D2.5mm_P7.62mm_Horizontal
R28, R29: 1k; R_Axial_DIN0207_L6.3mm_D2.5mm_P7.62mm_Horizontal
R30, R31: 100; R_Axial_DIN0207_L6.3mm_D2.5mm_P7.62mm_Horizontal
RV_HEADPHONE_LIM1: 10k; Potentiometer_Runtron_RM-065_Vertical
RV_LINE_OUT_LVL1: 100k; Potentiometer_Runtron_RM-065_Vertical
RV_MAIN_VOL1: A100k; NSL25_01x03_Vertical
U7: NE5532; DIP-8_W7.62mm_LongPads
U8: TL072; DIP-8_W7.62mm_LongPads

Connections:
-12V: C12.2, C14.2, U7.4 (V-), U8.4 (V-); also elsewhere on the board
/Output/AUDIO_IN: RV_LINE_OUT_LVL1.1; also elsewhere on the board
unnamed: D_NEGATIVE_LIMITER1.1 (K), R28.1, RV_MAIN_VOL1.1
unnamed: J_HEADPHONES1.T, R30.1, R31.1
unnamed: J_LINE_OUT1.T, R29.1, RV_MAIN_VOL1.2
unnamed: R29.2, RV_HEADPHONE_LIM1.1
unnamed: RV_HEADPHONE_LIM1.2, U7.3 (+)
unnamed: R31.2, U7.1, U7.2 (-), U7.5 (+)
unnamed: R30.2, U7.6 (-), U7.7
unnamed: R27.1, RV_LINE_OUT_LVL1.2, RV_LINE_OUT_LVL1.3, U8.5 (+)
unnamed: R28.2, U8.6 (-), U8.7

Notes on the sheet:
Sometimes there's an unwanted artifact of the VCF: when the resonance is turned up then the output starts out with a very negative value that normalizes in a short amount of time to oscillate around 0V. With each gate this results in a very sharp and big spike that is bad for the output. This diode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
Send and return path can be directly connected right before the main volumen pot.
Max line out level Set to 2.8Vpp
From VCA 10Vpp (To set output gain use the VCA gain trimmer)


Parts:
J_FILTER_INTERFACE_1: Conn_01x05; NSL25_01x05_Vertical
J_FILTER_IO1, J_FILTER_IO2: Conn_01x06; NSL25_01x06_Vertical
R46, R47, R48: 100k; R_Axial_DIN0207_L6.3mm_D2.5mm_P7.62mm_Horizontal
R62, R63, R64, R65: 100k

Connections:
/Filter Interface/AUDIO_IN: J_FILTER_INTERFACE_1.1; also elsewhere on the board
/Filter Interface/AUDIO_OUT: J_FILTER_INTERFACE_1.5; also elsewhere on the board
unnamed: J_FILTER_INTERFACE_1.2, R46.2, R47.2, R48.2

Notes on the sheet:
FILTER_POSITION is connected to the (extra) ADC so that the MCU knows what the actual filter setting is.
There are two fixed mod sources for filter: a potmeter for cutoff frequency and the digital filter mod (which is calculated by the MCU and is the output of channel B of the DAC). There's a rotary controller that sets various extra mod sources for filter cutoff: - LFO - Modwheel - Envelope - Velocit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
All this has to be wired on the UI.


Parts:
Q2: BC558; TO-92_Inline_Wide
Q3, Q4, Q5, Q6: BC548; TO-92_Inline_Wide
R49, R50, R53: 100k; R_Axial_DIN0207_L6.3mm_D2.5mm_P7.62mm_Horizontal
R51, R52: 22k; R_Axial_DIN0207_L6.3mm_D2.5mm_P7.62mm_Horizontal
R54, R57: 470; R_Axial_DIN0207_L6.3mm_D2.5mm_P7.62mm_Horizontal
R55, R56: 4.7k; R_Axial_DIN0207_L6.3mm_D2.5mm_P7.62mm_Horizontal
R58, R59: 33k; R_Axial_DIN0207_L6.3mm_D2.5mm_P7.62mm_Horizontal
RV_GATE_DAMP1: 100k; Potentiometer_Runtron_RM-065_Vertical
RV_REJECTION1: 10k; Potentiometer_Bourns_3296W_Vertical
RV_VCA_BIAS1: 100k; Potentiometer_Runtron_RM-065_Vertical
TP_VCA_AU_IN1: TestPoint; TestPoint_THTPad_D2.0mm_Drill1.0mm
TP_VCA_GATE1: TestPoint; TestPoint_THTPad_D2.0mm_Drill1.0mm
TP_VCA_OUT1: TestPoint; TestPoint_THTPad_D2.0mm_Drill1.0mm
U8: TL072; DIP-8_W7.62mm_LongPads

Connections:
-12V: Q3.3 (E), Q5.3 (E), R50.2; also elsewhere on the board
/VCA (Internal)/AUDIO_IN: R53.1; also elsewhere on the board
/VCA (Internal)/AUDIO_OUT: R59.2, TP_VCA_OUT1.1, U8.1; also elsewhere on the board
unnamed: Q2.1 (C), Q3.1 (C), Q3.2 (B), Q5.2 (B)
unnamed: Q2.3 (E), R51.2, R52.2, TP_VCA_GATE1.1
unnamed: Q4.2 (B), R53.2, R54.1, TP_VCA_AU_IN1.1
unnamed: Q4.1 (C), R55.1, R59.1, U8.2 (-)
unnamed: Q4.3 (E), Q5.1 (C), Q6.3 (E)
unnamed: Q6.2 (B), R57.1
unnamed: Q6.1 (C), R56.1, R58.2, U8.3 (+)
unnamed: R49.2, RV_VCA_BIAS1.1
unnamed: R50.1, RV_VCA_BIAS1.3
unnamed: R51.1, RV_GATE_DAMP1.2
unnamed: R52.1, RV_VCA_BIAS1.2
unnamed: R55.2, RV_REJECTION1.1
unnamed: R56.2, RV_REJECTION1.3

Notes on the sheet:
References: https://kassu2000.blogspot.com/2015/10/vca.html https://www.schmitzbits.de/vca.html
Max CV input voltage 5-12V
Calibration: - Connect audio on the input - Set RV_BIAS1 until you just can't hear anything on the output - Use RV_REJECTION1 to compensate DC offset if there's any.


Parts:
C1, C2, C3: 100n; C_Disc_D3.0mm_W2.0mm_P2.50mm
C27: 470n (foil); C_Rect_L7.0mm_W3.5mm_P5.00mm
D1: 1N4148; D_DO-35_SOD27_P7.62mm_Horizontal
J_MIDI_IN1: Conn_01x02; NSL25_01x02_Vertical
J_SWD_IO1: Conn_01x04; NSL25_01x04_Vertical
R1, R3: 220; R_Axial_DIN0207_L6.3mm_D2.5mm_P7.62mm_Horizontal
R2: 4.7k; R_Axial_DIN0207_L6.3mm_D2.5mm_P7.62mm_Horizontal
R4, R7: 100k; R_Axial_DIN0207_L6.3mm_D2.5mm_P7.62mm_Horizontal
R5: 200k; R_Axial_DIN0207_L6.3mm_D2.5mm_P7.62mm_Horizontal
R6: 22k; R_Axial_DIN0207_L6.3mm_D2.5mm_P7.62mm_Horizontal
R66, R67: 10k; R_Axial_DIN0207_L6.3mm_D2.5mm_P7.62mm_Horizontal
RV_ENV_GAIN1: 200k; Potentiometer_Runtron_RM-065_Vertical
TP_ENV_OUT1: TestPoint; TestPoint_THTPad_D2.0mm_Drill1.0mm
TP_FILT_MOD1: TestPoint; TestPoint_THTPad_D2.0mm_Drill1.0mm
U1: Pico; RPi_Pico_SMD_TH
U2: 6N138; DIP-8_W7.62mm_LongPads
U3: TL072; DIP-8_W7.62mm_LongPads
U4: CD4051B; DIP-16_W7.62mm_LongPads
U5: MCP4822; DIP-8_W7.62mm_LongPads

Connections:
+5V: J_SWD_IO1.3, U1.39 (VSYS), U5.1 (Vdd); also elsewhere on the board
-12V: C2.2, U3.4 (V-); also elsewhere on the board
/Digital/AMP_1: U1.27 (GPIO21); also elsewhere on the board
/Digital/AMP_2: U1.26 (GPIO20); also elsewhere on the board
/Digital/AMP_3: U1.25 (GPIO19); also elsewhere on the board
/Digital/AMP_4: U1.24 (GPIO18); also elsewhere on the board
/Digital/AMP_5: U1.22 (GPIO17); also elsewhere on the board
/Digital/AMP_6: U1.21 (GPIO16); also elsewhere on the board
/Digital/Digital UI/EXTRA_GPIO1: U1.34 (GPIO28_ADC2); also elsewhere on the board
/Digital/Digital UI/EXTRA_GPIO2: U1.29 (GPIO22); also elsewhere on the board
/Digital/RESET_1: U1.14 (GPIO10); also elsewhere on the board
/Digital/RESET_2: U1.15 (GPIO11); also elsewhere on the board
/Digital/RESET_3: U1.16 (GPIO12); also elsewhere on the board
/Digital/RESET_4: U1.17 (GPIO13); also elsewhere on the board
/Digital/RESET_5: U1.19 (GPIO14); also elsewhere on the board
/Digital/RESET_6: U1.20 (GPIO15); also elsewhere on the board
DAC_CS: U1.7 (GPIO5), U5.2 (~CS)
DAC_SCK: U1.9 (GPIO6), U5.3 (SCK)
DAC_SDI: U1.10 (GPIO7), U5.4 (SDI)
MIDI_IN: R3.2, U1.12 (GPIO9), U2.6 (VO2)
MUX_A: U1.6 (GPIO4), U4.11 (A)
MUX_B: U1.5 (GPIO3), U4.10 (B)
MUX_BINARY: U1.11 (GPIO8), U4.3 (X)
MUX_C: U1.4 (GPIO2), U4.9 (C)
unnamed: D1.2 (A), J_MIDI_IN1.2, U2.3 (C2)
unnamed: D1.1 (K), R1.2, U2.2 (C1)
unnamed: J_MIDI_IN1.1, R1.1
unnamed: R6.2, RV_ENV_GAIN1.2, RV_ENV_GAIN1.3
unnamed: R2.1, U2.7 (VO1)
unnamed: U3.3 (+), U5.8 (VA)
unnamed: R4.1, R6.1, U3.2 (-)
unnamed: U3.5 (+), U5.6 (VB)
unnamed: R5.1, R7.1, U3.6 (-)
unnamed 84: C27.2, R66.2, R67.2; also elsewhere on the board
UART_RX: J_SWD_IO1.2, U1.2 (GPIO1)
UART_TX: J_SWD_IO1.1, U1.1 (GPIO0)

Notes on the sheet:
Low pass filter to filter out digital noise on envelope and filter mod outs.
This is a calculated value based on keyboard tracking state and whether the wah source is velocity.
Envelope maximum: about 5-12V. Calibration: 1. set an envelope value that sounds good for the filter cutoff mod 2. use GATE_DAMP in VCA to damp the envelope that controls the VCA

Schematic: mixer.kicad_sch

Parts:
C4, C5, C6, C7: 22p; C_Disc_D3.0mm_W2.0mm_P2.50mm
C8, C27, C28: 470n (foil); C_Rect_L7.0mm_W3.5mm_P5.00mm
C9, C10: 100n; C_Disc_D3.0mm_W2.0mm_P2.50mm
R8, R9, R10, R11, R12, R13, R14, R15, R16, R17, R18, R19, R22, R23, R24, R25: 100k; R_Axial_DIN0207_L6.3mm_D2.5mm_P7.62mm_Horizontal
R20: 47k; R_Axial_DIN0207_L6.3mm_D2.5mm_P7.62mm_Horizontal
R21: 33k; R_Axial_DIN0207_L6.3mm_D2.5mm_P7.62mm_Horizontal
R26: 1M; R_Axial_DIN0207_L6.3mm_D2.5mm_P7.62mm_Horizontal
SW_WAVESHAPE1: SW_SPDT; NSL25_01x03_Vertical
TP_SAW_SUBMIX1: TestPoint; TestPoint_THTPad_D2.0mm_Drill1.0mm
TP_SQR_SUBMIX1: TestPoint; TestPoint_THTPad_D2.0mm_Drill1.0mm
U6: TL074; DIP-14_W7.62mm_LongPads

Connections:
-12V: C10.2, U6.11 (V-); also elsewhere on the board
/Filter Interface/AUDIO_IN: C8.2, R26.1; also elsewhere on the board
/Mixer/SAW_1_IN: R8.1; also elsewhere on the board
/Mixer/SAW_2_IN: R9.1; also elsewhere on the board
/Mixer/SAW_3_IN: R10.1; also elsewhere on the board
/Mixer/SAW_4_IN: R11.1; also elsewhere on the board
/Mixer/SAW_5_IN: R12.1; also elsewhere on the board
/Mixer/SAW_6_IN: R13.1; also elsewhere on the board
/Mixer/SQR_1_IN: R14.1; also elsewhere on the board
/Mixer/SQR_2_IN: R15.1; also elsewhere on the board
/Mixer/SQR_3_IN: R16.1; also elsewhere on the board
/Mixer/SQR_4_IN: R17.1; also elsewhere on the board
/Mixer/SQR_5_IN: R18.1; also elsewhere on the board
/Mixer/SQR_6_IN: R19.1; also elsewhere on the board
unnamed: C4.2, R20.2, R22.1, U6.1
unnamed: C5.2, R21.2, R23.1, U6.8
unnamed: C28.1, R14.2, R15.2, R16.2, R17.2, R18.2, R19.2
unnamed: C6.2, R24.2, SW_WAVESHAPE1.1 (A), TP_SAW_SUBMIX1.1, U6.7
unnamed: C8.1, SW_WAVESHAPE1.2 (B)
unnamed: C7.2, R25.2, SW_WAVESHAPE1.3 (C), TP_SQR_SUBMIX1.1, U6.14
unnamed 84: C4.1, C27.2, R20.1, U6.2 (-); also elsewhere on the board
unnamed: C6.1, R22.2, R24.1, U6.6 (-)
unnamed: C5.1, C28.2, R21.1, U6.9 (-)
unnamed: C7.1, R23.2, R25.1, U6.13 (-)

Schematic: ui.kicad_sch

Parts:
J_UI1, J_UI2: Conn_01x06; NSL25_01x06_Vertical
J_UI3: Conn_01x02; NSL25_01x02_Vertical
R60, R61: 100k; R_Axial_DIN0207_L6.3mm_D2.5mm_P7.62mm_Horizontal

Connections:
/Digital/Digital UI/EXTRA_GPIO1: J_UI3.1; also elsewhere on the board
/Digital/Digital UI/EXTRA_GPIO2: J_UI3.2; also elsewhere on the board

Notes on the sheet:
Value voltages (GND, 3.3V and 1.5V) are connected with wires between switches. By default the [mux] input of the MCU is pulled up.
These could be NTF connectors, or ribbon cables too. Maybe it's better to add both?

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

Board: 2 copper layers, 242.5 x 102.5 mm, 163 parts (0 on the bottom side), 131 nets.

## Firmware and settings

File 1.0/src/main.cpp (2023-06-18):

/*
 * shmoergh-funk-live for Raspberry Pi Pico
 *
 * @version     1.0.0
 * @author      Peter Zimon — peter.zimon@gmail.com
 * @copyright   2023
 * @licence     MIT
 *
 *          ---------------------------------------------------
 *          |       USE ONLY USB POWER WHEN FLASHING!!!!      |
 *          ---------------------------------------------------
 *
 * Classes
 * -------
 *      Synth: MidiParser
 *          - parses incoming MIDI data
 *          - updates DCO frequencies and amp levels
 *
 *      IConverter
 *          - interface for different converters (modes). Converter
 *            implementations are in ./converters
 *
 *      UI
 *          - handles the interface, LEDs and stuff
 *
 * @TODO:
 *
 * - paraphonic logic works!! YAY! clean up debug/printf calls once all done
 * - test DCOs
 */

/*
 * C++ headers
 */
#include <iostream>
#include <string>
#include <vector>
#include <cstdlib>
#include <cstdint>
#include <cstring>

/*
 * Pico headers
 */
#include "pico/stdlib.h"
#include "pico/binary_info.h"
#include "hardware/gpio.h"
#include "hardware/spi.h"
#include "hardware/uart.h"
#include "hardware/pio.h"
#include "hardware/clocks.h"
#include "frequency.pio.h"

/*
 * Custom libraries
 */
#include <utils.h>

/*
 * Project headers
 */
#include "ui.h"
#include "synth.h"
#include "settings.h"

/**
 * Classes
*/
Settings settings;
Synth &synth = Synth::get_instance();
UI &ui = UI::get_instance();

PIO pio = pio0;
uint sm = pio_claim_unused_sm(pio, true);

int main() {
    stdio_init_all();

    printf("\n\n--- SHMØERGH FUNK LIVE ONE ---\r\n\n");

    // Init PIOs: they must be initialised here in main.cpp
    uint offset[2];
    offset[0] = pio_add_program(settings.pio[0], &frequency_program);
    offset[1] = pio_add_program(settings.pio[1], &frequency_program);

    for (int i = 0; i < VOICES; i++) {
        init_sm_pin(settings.pio[settings.voice_to_pio[i]],
                    settings.voice_to_sm[i],
                    offset[settings.voice_to_pio[i]],
                    settings.reset_pins[i]);
        pio_sm_set_enabled(settings.pio[settings.voice_to_pio[i]], settings.voice_to_sm[i], true);
    }

    // Initialise UI
    ui.init();

    // We need to wait a bit before the first read because of the Pico's GPIO speed
    sleep_ms(1000);
    ui.init_scan();

    // Initialise synth
    synth.init(PARA);
    synth.init_dcos();

    // Test -------------------------------
    // synth.set_adsr(false, true, false);
    // synth.set_solo(false);
    // synth.set_detune(true);
    // synth.set_portamento(false);
    // synth.set_kb_tracking(true);
    // synth.set_velo_tracking(true);
    // ------------------------------------

    // Main update loop
    while (1) {
        ui.scan();
        synth.process();
    }

    return 0;
}

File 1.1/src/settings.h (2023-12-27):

#ifndef _SETTINGS_H
#define _SETTINGS_H

#include <inttypes.h>
#include <pico/stdio.h>
#include "hardware/spi.h"
#include "hardware/uart.h"
#include "hardware/pio.h"

// GLOBAL
#define VOICES              6
#define FAT_MONO_VOICES     3
#define PARA_STACK_VOICES   false
#define DEFAULT_FREQ        220.0
#define MAX_FREQ            5000.0      // This depends on the integrator's RC constant.
                                        // Rint = 200kohm, Cint = 1nF
                                        // fmax = 1/RC = 5kHz
                                        // Change this value if you change any of
                                        // the above components in the circuit.
#define LOWEST_MIDI_NOTE    21          // A0. This is needed otherwise the DCO can
                                        // get in a stuck state when a too low note
                                        // is played.

#define PORTAMENTO_TIME     10
#define DETUNE_FACTOR       1.02f       // Only available in FAT mode, should be > 1

#define ENVELOPE_DAC_SIZE   4096
#define FILTER_MOD_DAC_SIZE 4096

#define VELO_FACTOR         24          // Velocity is used to mod the filter (if it's
                                        // turned on), with the formula:
                                        // Vmod = VELOCITY * VELO_FACTOR [mV]
                                        // (0 < VELOCITY < 127)
                                        // Since the max output is 4096mV and there
                                        // should be some space for other mod sources
                                        // it's maximised in about 3V (when velo = 127)

// ADSR (all time values are in us)
#define ATTACK_SHORT        3500
#define ATTACK_LONG         210000
#define DECAY_SHORT         500000
#define DECAY_MID           1500000
#define DECAY_LONG          23000000
#define DECAY_LONG_MIN      75          // * 100000 = min decay long
#define DECAY_LONG_MAX      230         // * 100000 = max decay long
#define SUSTAIN_ON          3600            // mV, between 0 and 4095
#define SUSTAIN_OFF         0               // mV, between 0 and 4095
#define RELEASE_SHORT       500000
#define RELEASE_LONG_MIN    50              // * 100000 = min release in us
#define RELEASE_LONG_MAX    300             // * 100000 = max release in us

// Keyboard tracking. There's a min and max frequency in between keyboard is
// tracked and changes the cutoff. Below it, tracking is off, above it it's
// fully open. The factor sets how much tracking should open cutoff. This is
// set so that at 1760Hz it sets the DAC to it's max value (4096/1760 = 2.32).
#define KB_TRACK_MIN_FREQ   55
#define KB_TRACK_MAX_FREQ   1760
#define KB_TRACK_FACTOR     2.3

// DAC
#define DAC_SPI_PORT        spi0
#define GP_DAC_SCK          6
#define GP_DAC_MOSI         7
#define GP_DAC_CS           5

// MIDI
#define MIDI_CHANNEL                4
#define OCTAVES                     10
#define MIDI_UART_INSTANCE          uart1
#define GP_MIDI_RX                  9
#define MIDI_BAUDRATE               31250
#define MIDI_OCTAVE_SHIFT           0 // Not implemented
#define PITCH_BEND_SEMITONES        1 // Min. 1

// UI
#define MUX_BINARY_PIN_A            4
#define MUX_BINARY_PIN_B            3
#define MUX_BINARY_PIN_C            2
#define MUX_BINARY_INPUT            8
#define ADC_RING_LEN_PIN            27
#define ADC_RING_LEN_CHANNEL        1
#define ADC_SYNTH_MODE_PIN          26
#define ADC_SYNTH_MODE_CHANNEL      0
#define ENABLE_CHORD_MEMORY         false
#define BTN_CHORD                   22
#define LED_CHORD                   28

// Switches in the order how they're connected to the MUX
#define NO_OF_SWITCHES              8
enum mux_switch {
    SOFT,
    HOLD,
    RING,
    PORTAMENTO,
    DETUNE,
    SOLO_CHORD,
    KB_TRACKING,
    WAH_VELOCITY
};

#define NO_OF_MODES 3
enum device_mode {
    MONO,
    FAT_MONO,
    PARA
};

// PWM division counter
const uint16_t DIV_COUNTER = 1250;

struct Settings
{
    device_mode mode;

    // Solo is a submode of paraphonic mode. If it's off then the all played
    // voices will be on until the first voice is pressed again (the first
    // voice controls the gate to the envelope). When solo is _on_ then non-
    // first voices will turn off when their respective key is released.
    bool solo = false;
    bool portamento = false;
    bool detune = false;
    bool kb_tracking = false;
    bool velo_tracking = false;

    const uint8_t midi_channel = 0;
    const uint8_t voices = 6;

    const uint8_t reset_pins[VOICES] = {10, 11, 12, 13, 14, 15};
    const uint8_t amp_pins[VOICES] = {21, 20, 19, 18, 17, 16};
    const uint8_t voice_to_pio[VOICES] = {0, 0, 0, 0, 1, 1};
    const uint8_t voice_to_sm[VOICES] = {0, 1, 2, 3, 0, 1};

    // Two PIOs with 6 state machines (4 and 2) are used to set the frequency of the DCOs
    const PIO pio[2] = {pio0, pio1};
};

extern Settings settings;

#endif

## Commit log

2023-05-06 Added schematics for minimal version
    This version distributes the played notes equally between the available voices.
    [adsr.kicad_sch, digital.kicad_sch, discrete-vca.kicad_sch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]
2023-05-07 Added pico-lib submodule to the project.
2023-05-07 Added fundamentals based on Borneborn
    - copied base classes
    - removed class attachments in favor of singletons
2023-05-09 Added time based paraphonic converter
    [shmoergh-funk-live-voice.kicad_sch]
2023-05-09 Fixed div by 0 bug
    [synth.cpp]
2023-05-10 Updated DCO pins
    [digital.kicad_sch, discrete-vca.kicad_sch, filter-interface.kicad_sch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]
2023-05-10 Updated paraphonic logic
    The original idea was _almost_ good. The only change it needed is to
    reset _all the voices_ to the same note on every "first" key press, ie.
    once all the keys are released and then a new key is pressed. After this
    distrubute the notes evenly just like before.
    [main.cpp, settings.h, synth.cpp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]
2023-05-14 Fixed a mono bug and tested DCO resets (works)
    [main.cpp, settings.h, synth.cpp]
2023-05-22 Minor updates
    [shmoergh-funk-live-voice.kicad_sch]
2023-05-26 Updated DCO
    [shmoergh-funk-live-voice.kicad_sch]
2023-05-27 Updated f=0 amplitude compensation
    Until now if the frequency of a given voice was f=0Hz then I've set both
    the DCO freq. and the amplitude compensation to zero. This however
    resulted a negative DC offset on the output of the DCO. Instead if I set
    _only_ the amplitude to zero (and use another voice's frequency to
    reset the given DCO) then the DC output is closer to 0 which helps
    minimising the pop when voices are turned on.
    [synth.cpp]
2023-05-27 DCO schematic update
    Changed the DCO design from using a PNP transistor for the switch,
    positive charge and an inverting amp with bias for the saw output. This
    allows to bias the sawtooth output to oscillate around 0V which makes
    possible to set precise pulse width values for all voices regardless of
    potential component differences. Also, this eventually needs less
    component altogether.
    [shmoergh-funk-live-control.kicad_sch, shmoergh-funk-live-voice.kicad_sch]
2023-05-27 Added a couple of test points
    [shmoergh-funk-live-voice.kicad_sch]
2023-05-27 DCO schematic cleanup
    [shmoergh-funk-live-voice.kicad_sch]
2023-05-28 Added pulse width mod schematics
    [digital.kicad_sch, discrete-vca.kicad_sch, filter-interface.kicad_sch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]
2023-05-29 Updated PWM values
    [lfo.kicad_sch, shmoergh-funk-live-voice.kicad_sch]
2023-06-03 Added digital ADSR (untested)
    [shmoergh-funk-live-voice-B_Cu.gbl, shmoergh-funk-live-voice-B_Mask.gbs, shmoergh-funk-live-voice-B_Paste.gbp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]
2023-06-04 Updated ADSR code and DAC schem.
    [digital.kicad_sch]
2023-06-11 Updated VCA
    [digital.kicad_sch, discrete-vca.kicad_sch, filter-interface.kicad_sch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]
2023-06-11 Coded portamento (untested)
    [digital.kicad_sch]
2023-06-11 Added keyboard tracking DAC (untested)
    [shmoergh-funk-live-control.kicad_sch]
2023-06-11 Updated kb tracking for analog switch
    [digital.kicad_sch]
2023-06-11 Added all UI components to schematics
    - digital UI
    - filter UI
    - updated voice interface connection
    - simplified schematics a lot
    [digital-ui.kicad_sch, digital.kicad_sch, discrete-vca.kicad_sch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]
2023-06-11 Basic mono & para modes tested and working
2023-06-11 Implemented velocity filter mod
2023-06-11 Refined voice values
    [digital.kicad_sch, shmoergh-funk-live-voice.kicad_sch]
2023-06-18 Added switch MUX (untested)
2023-06-18 Updated MUX reading
    For some reason I couldn't figure out yet, there was one step offset
    in the reading of the multiplexer input. :/ Now it works as intended
    but it's still annoying.
    [digital.kicad_sch, ui.kicad_sch]
2023-06-18 Added mode switch
2023-06-18 Added pitch bend to MONO + UNISON
2023-06-18 Added pitch bend to paraphonic mode
2023-06-20 Schemo work
    [digital.kicad_sch, discrete-vca.kicad_sch, filter-interface.kicad_sch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]
2023-06-24 Simplified PWM switch IO
    [lfo.kicad_sch, output.kicad_sch, shmoergh-funk-live-control.kicad_pcb]
2023-06-25 Updated schem. + added JLCPCB gerbers
    [digital.kicad_sch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]
2023-07-02 Panel graphics update
    [wooden-case-proto.blend]
2023-07-09 1.0 bugfixes
    [digital.kicad_sch]
2023-07-09 Added 1.1
    [adsr.kicad_sch, digital-ui.kicad_sch, digital.kicad_sch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]
2023-07-09 Updated 1.1 mixer level
    [mixer.kicad_sch]
2023-07-10 ✨ 1.1 Release
    Hardware
    - Fixes missing capacitor on the inputs of mixers. At f=0Hz the DCO's produce a DC output which shifts the center point of DCO's where f>0Hz. This happens on both the sawtooth and the squarewave output. A 470nF foil capacitor blocks all DC input on the input of the mixers.
    - Decreases the aplification of mixers. The sum of 6 voices on both saw and square mixers are way too strong and hit the op-amp limits (+/-12V). The first stage of the mixers are reduced now to 1/3 on the squarewave and 1/2 on the sawtooth. Sounds much smoother!
    Software
    - Updates the MUX and the amp compensation output pin numbers according to the schematics.
    [mixer.kicad_sch, shmoergh-funk-live-control.kicad_pcb]
2023-07-10 Added pico-lib as a submodule to 1.0
2023-07-10 Added pico-lib as a submodule to 1.1
2023-08-12 Updates to 1.0
    [filter-interface.kicad_sch, lfo.kicad_sch]
2023-08-12 1.1 changes
    [digital.kicad_sch, filter-interface.kicad_sch, lfo.kicad_sch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]
2023-08-13 Digital filter mod updates
    - added fixed modwheel control
    - fixed velocity and keyboard tracking bug
    [settings.h, synth.cpp, ui.cpp]
2023-08-18 Added SMD voice
    [adsr.kicad_sch, digital-ui.kicad_sch, digital.kicad_sch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]
2023-08-31 Removed a bunch of unnecessary backups
    [adsr.kicad_sch, digital-ui.kicad_sch, digital.kicad_sch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]
2023-09-08 Copy code 1.0 to 1.1
    [adsr.kicad_sch, digital-ui.kicad_sch, digital.kicad_sch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]
2023-09-08 pico lib changes
2023-09-09 Using kicad-libs submodule in 1.1
2023-09-09 Updated footprint links
    [steiner-parker-vcf.kicad_pcb]
2023-09-09 Fixed ADC channel number bug
    [settings.h, ui.cpp]
2023-09-09 Added sound source UI
    [sound-source-ui.kicad_pcb, sound-source-ui.kicad_sch, ui.kicad_sch]
2023-09-10 Added envelope UI connections
    [sound-source-ui.kicad_pcb, sound-source-ui.kicad_sch]
2023-09-10 Added envelope UI
    [envelope-ui.kicad_pcb, envelope-ui.kicad_sch]
2023-09-10 Made sound source UI PCB narrower
    [sound-source-ui.kicad_pcb]
2023-09-10 Made envelope UI narrower
    [envelope-ui.kicad_pcb, envelope-ui.kicad_sch]
2023-09-10 Envelope UI refinements
    [envelope-ui.kicad_sch]
2023-09-11 Updated envelope UI and filter
    [envelope-ui.kicad_pcb, sound-source-ui.kicad_pcb, vcf.kicad_sch]
2023-09-16 Added UI PCB's
    [keyboard-tracking-ui.kicad_pcb, keyboard-tracking-ui.kicad_sch, octave-ui.kicad_pcb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]
2023-09-16 Added chord logic (untested)
    [octave-ui.kicad_pcb, octave-ui.kicad_sch]
2023-12-26 Added UI PCB design
2023-12-27 Added MIDI channel (fixed to CH5) condition
    [settings.h, synth.cpp]
